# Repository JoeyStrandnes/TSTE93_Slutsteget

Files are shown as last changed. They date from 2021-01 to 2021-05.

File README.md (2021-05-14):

# TSTE93_Slutsteget
Projekt för kursen TSTE93

### Electronics

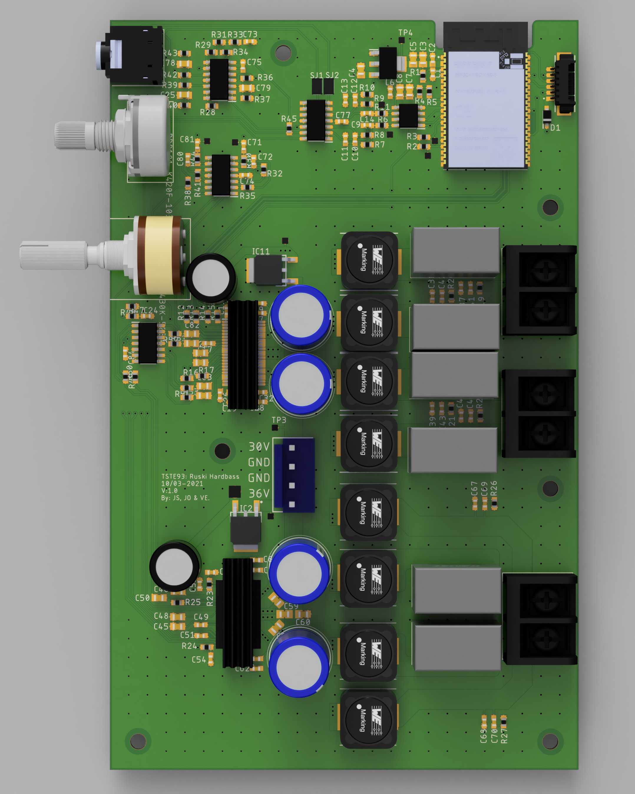
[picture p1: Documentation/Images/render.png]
Render


### Case

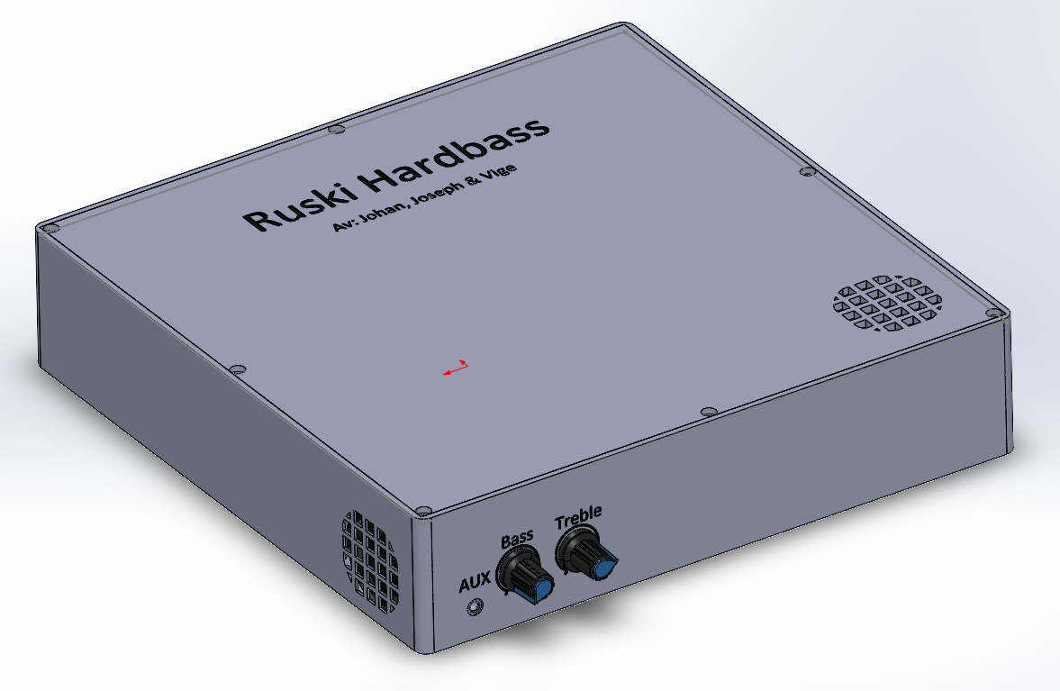
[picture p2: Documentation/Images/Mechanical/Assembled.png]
Case


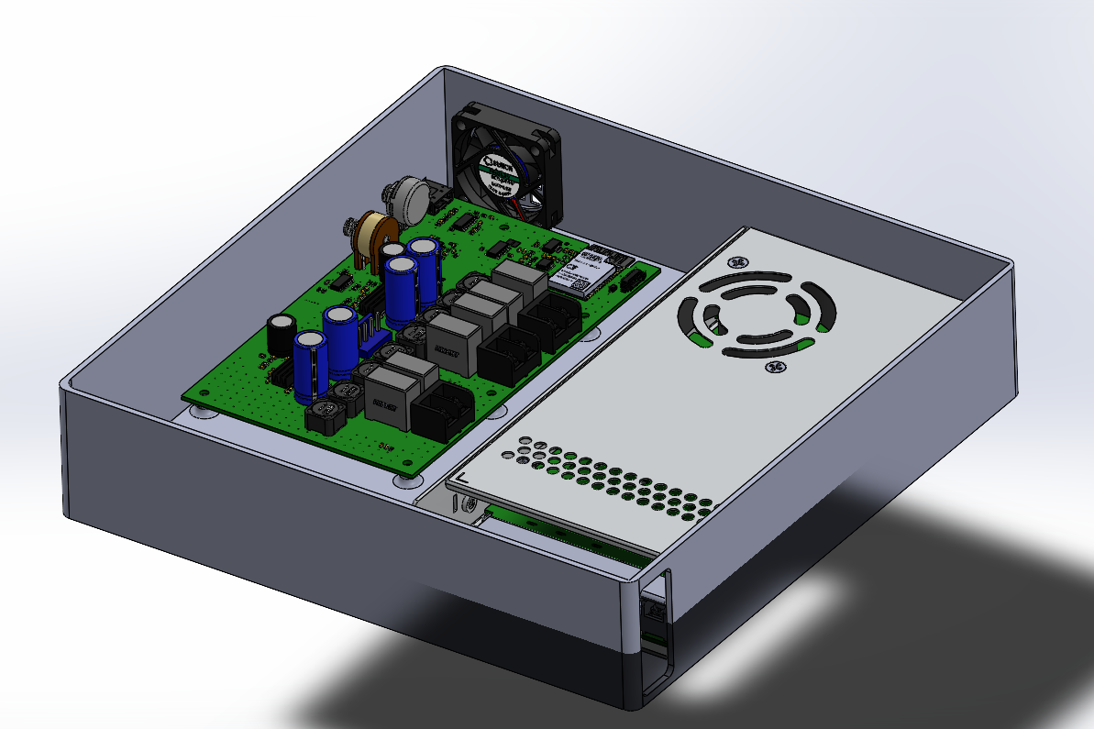
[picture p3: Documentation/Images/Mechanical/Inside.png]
Inside


### Functional diagram

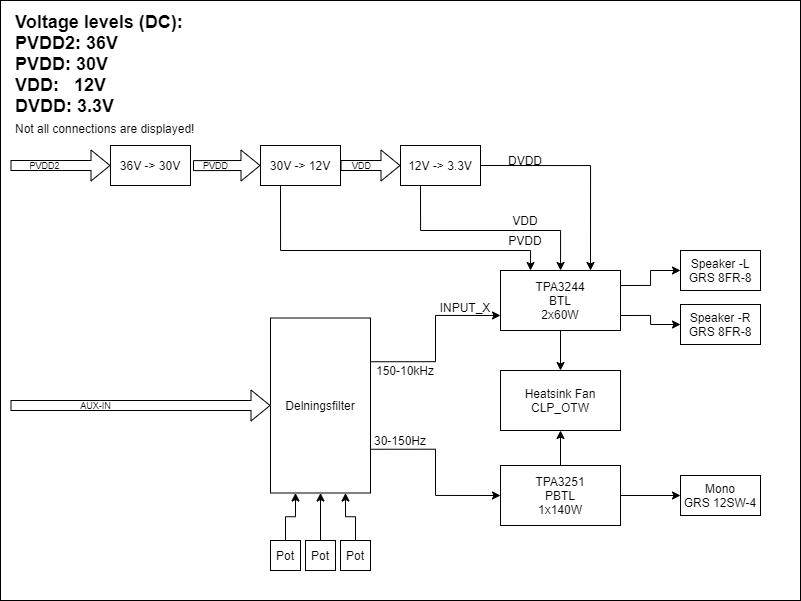
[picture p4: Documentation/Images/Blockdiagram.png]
Overview


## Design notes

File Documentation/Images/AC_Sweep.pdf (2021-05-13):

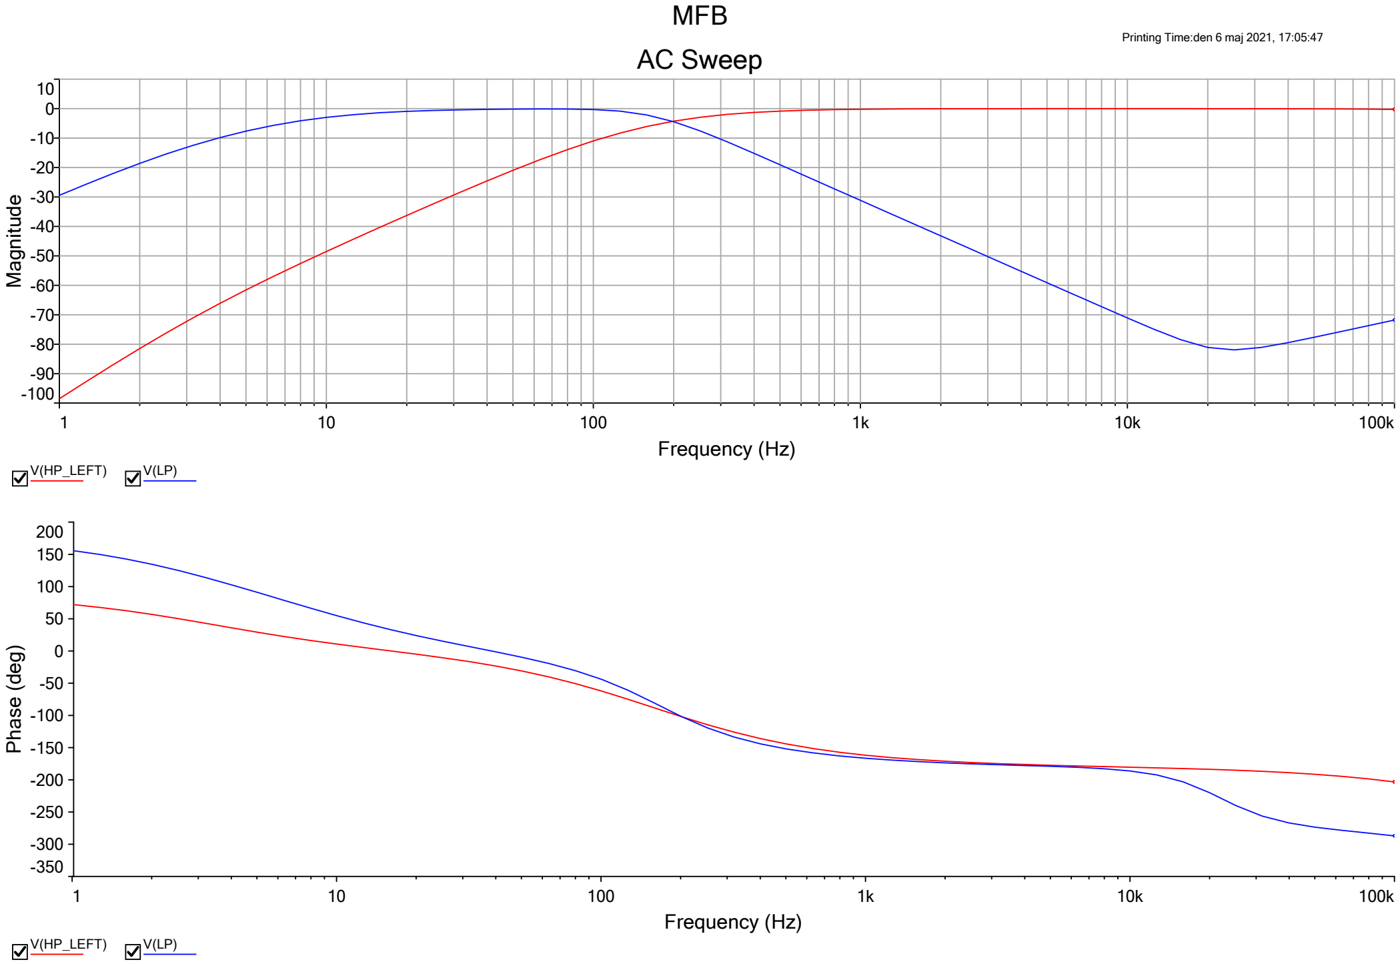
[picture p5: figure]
MFB; Printing Time:den 6 maj 2021, 17:05:47; V(HP_LEFT); AC Sweep; Frequency (Hz); 100k Magnitude; 100k Phase ⁽deg⁾

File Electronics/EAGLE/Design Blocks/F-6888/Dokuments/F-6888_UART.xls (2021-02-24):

UART通讯命令
模式 |  | 事件 | 指令 | 备注
LINEIN 模式 | RX | play/pause | BE 00 00 00 0c EB
 | RX | vol- | BE 00 00 00 12 EB
 | RX | vol+ | BE 00 00 00 13 EB
BT模式 | RX | play/pause | BE 00 00 00 0c EB
 | RX | next | BE 00 00 00 11 EB
 | RX | previous | BE 00 00 00 10 EB
 | RX | answer call | BE 00 00 00 16 EB
 | RX | cancel call | BE 00 00 00 16 EB
 | RX | reject call | BE 00 00 80 16 EB
 | RX | dial the last number | BE 00 00 20 16 EB
FM模式 | RX | vol- | BE 00 00 00 12 EB
 | RX | vol+ | BE 00 00 00 13 EB
 | RX | auto search | BE 00 00 00 0c EB
 | RX | NEXT channel | BE 00 00 00 11 EB
 | RX | PREV channel | BE 00 00 00 10 EB
 | RX | 0.1M NEXT tune | BE 00 00 00 21 EB
 | RX | 0.1M PREV tune | BE 00 00 00 22 EB
 | RX | find NEXT one and stop | BE 00 00 00 23 EB
 | RX | find PREV one and stop | BE 00 00 00 24 EB
 | RX | 请求读当前频率命令 | BE 70 00 00 06 EB
 | TX | 返馈给MCU频率值命令(TX) | BE 80 00 value2 value1 EB | 如101.6Mhz:发送值为1016，十六进制为0x3f8。则value1=0xf8;value2 = 0x03。
 | RX | 跳转到特定FM | BE 71 00 value2 value1 EB
 | RX | 请求读保存频道的信息 | BE 70 00 00 07 EB
其它命令 | RX | 请求读取当前模式命令 | BE 70 00 00 08 EB
 | RX | ENTER BT MODE | BE 70 00 00 01 EB(开机默认)
 | RX | ENTER U MODE | BE 70 00 00 02 EB
 | RX | ENTER SD MODE | BE 70 00 00 03 EB
 |  | ENTER FM MODE | BE 70 00 00 04 EB
 |  | ENTER AUX MODE | BE 70 00 00 05 EB

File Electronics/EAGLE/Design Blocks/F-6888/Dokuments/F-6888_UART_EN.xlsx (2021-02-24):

Mode |  | Event | Command | Notes
LINE IN | RX | Play/ pause

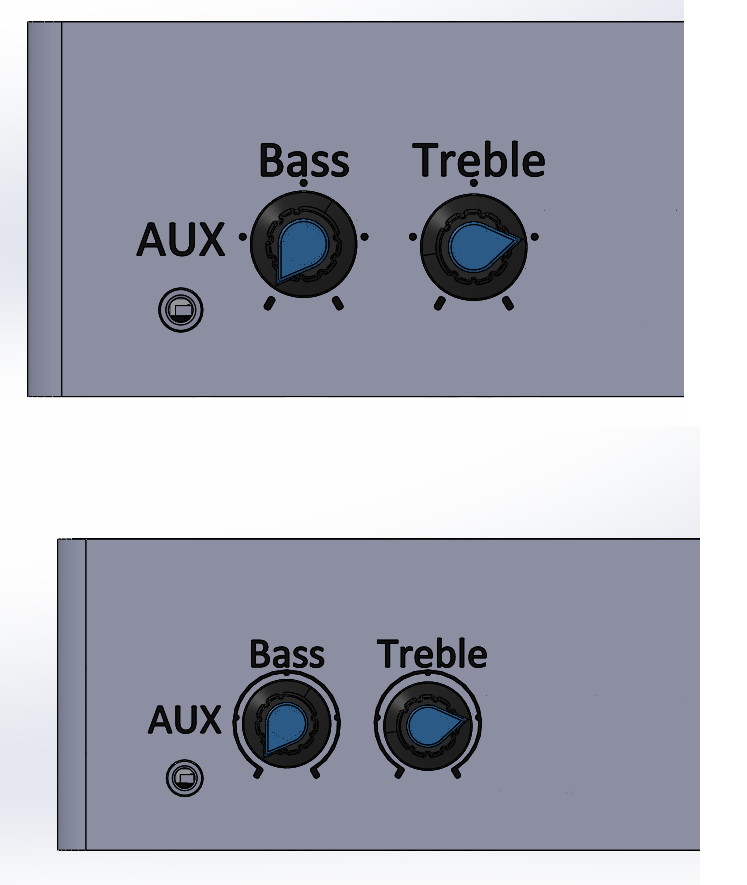
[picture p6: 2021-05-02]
Documentation/Images/Mechanical/Knobs.png

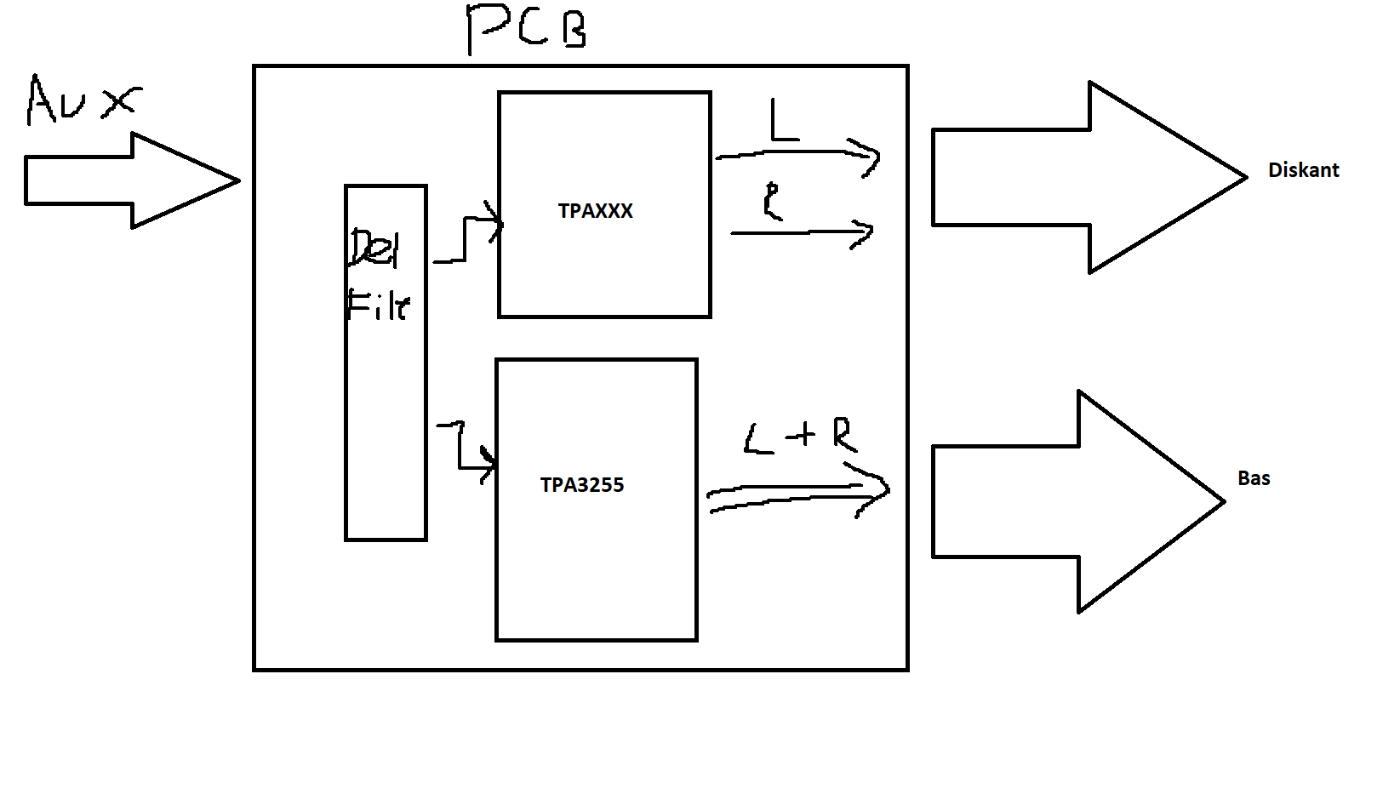
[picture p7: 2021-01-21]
Documentation/Images/Functional Overview.png

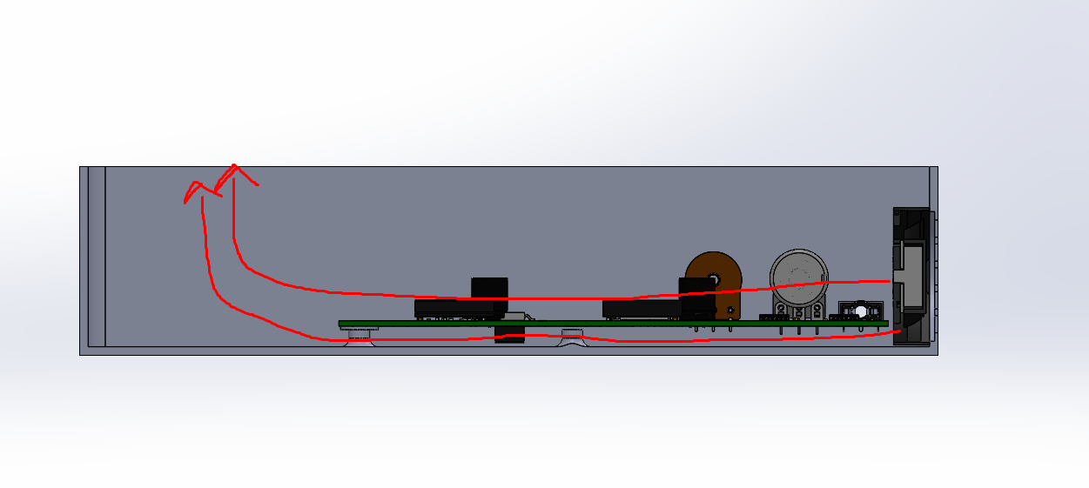
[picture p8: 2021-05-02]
Documentation/Images/Mechanical/Air_Flow.png

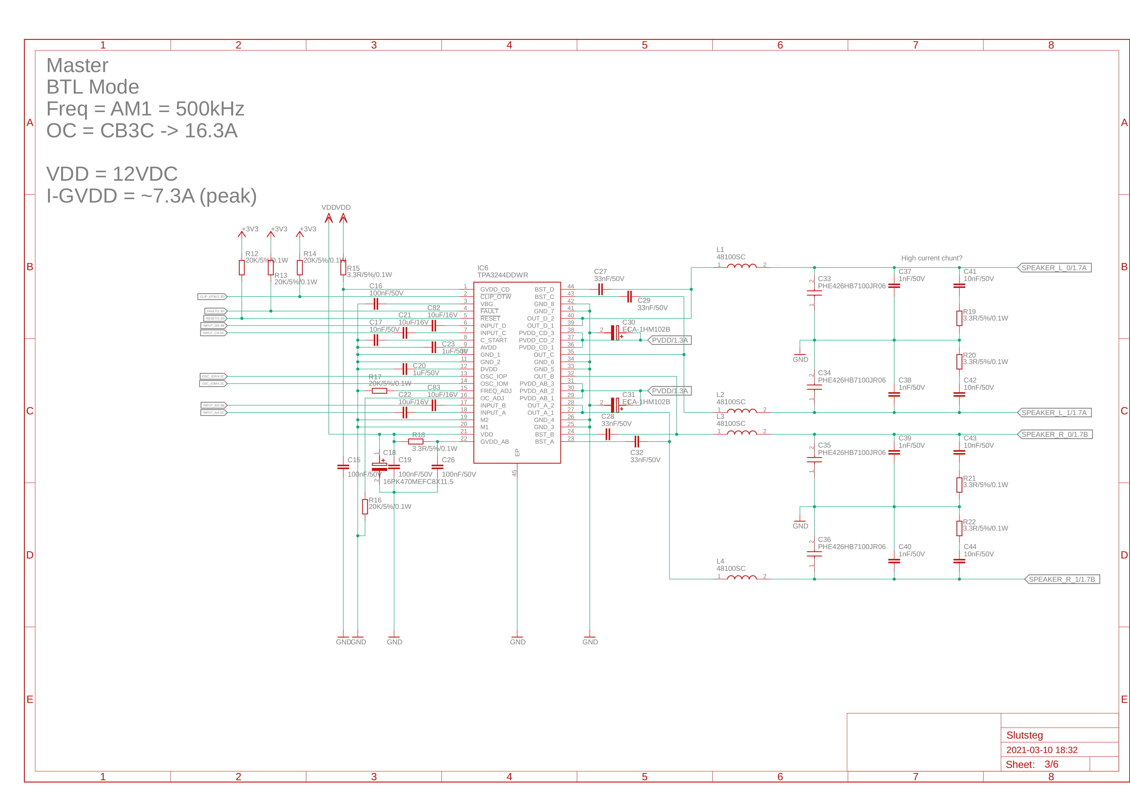
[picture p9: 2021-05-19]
Documentation/Schematic/Schematic-3.jpg

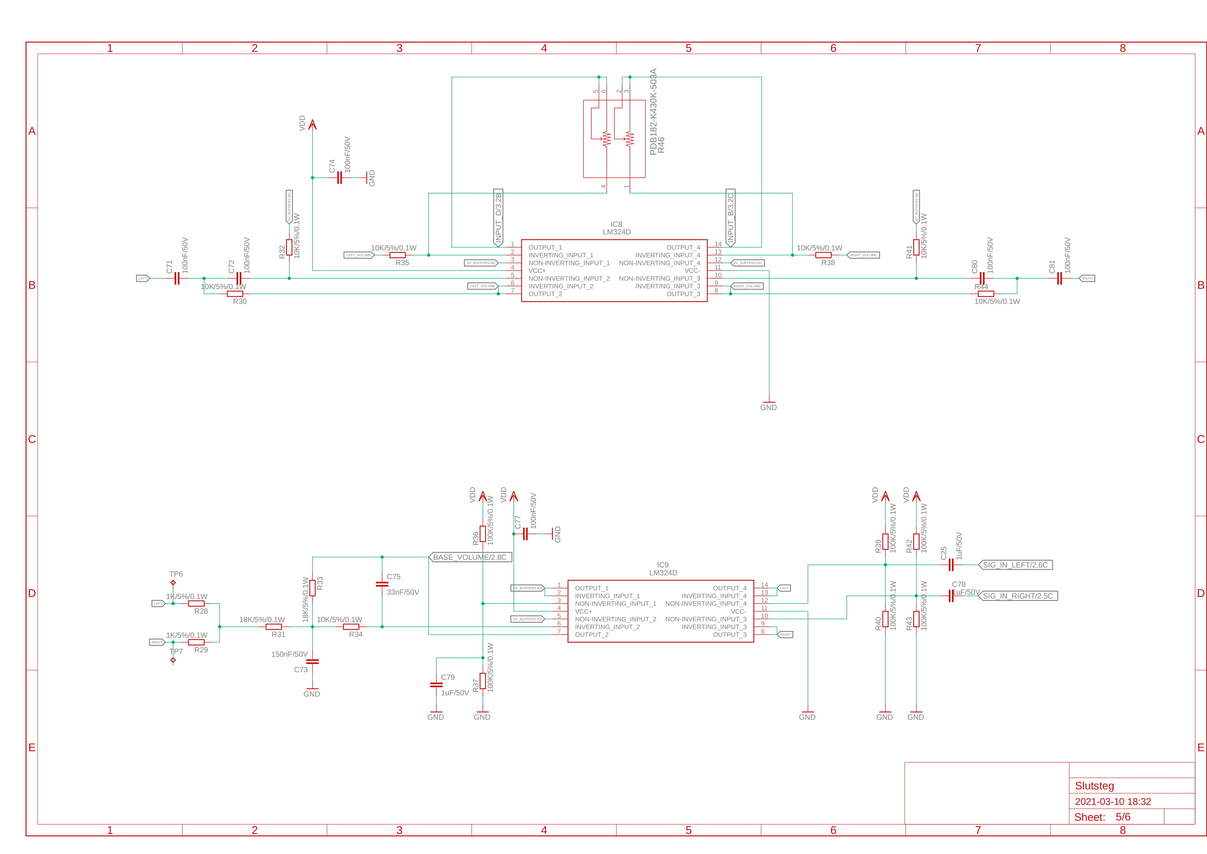
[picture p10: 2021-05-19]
Documentation/Schematic/Schematic-5.jpg

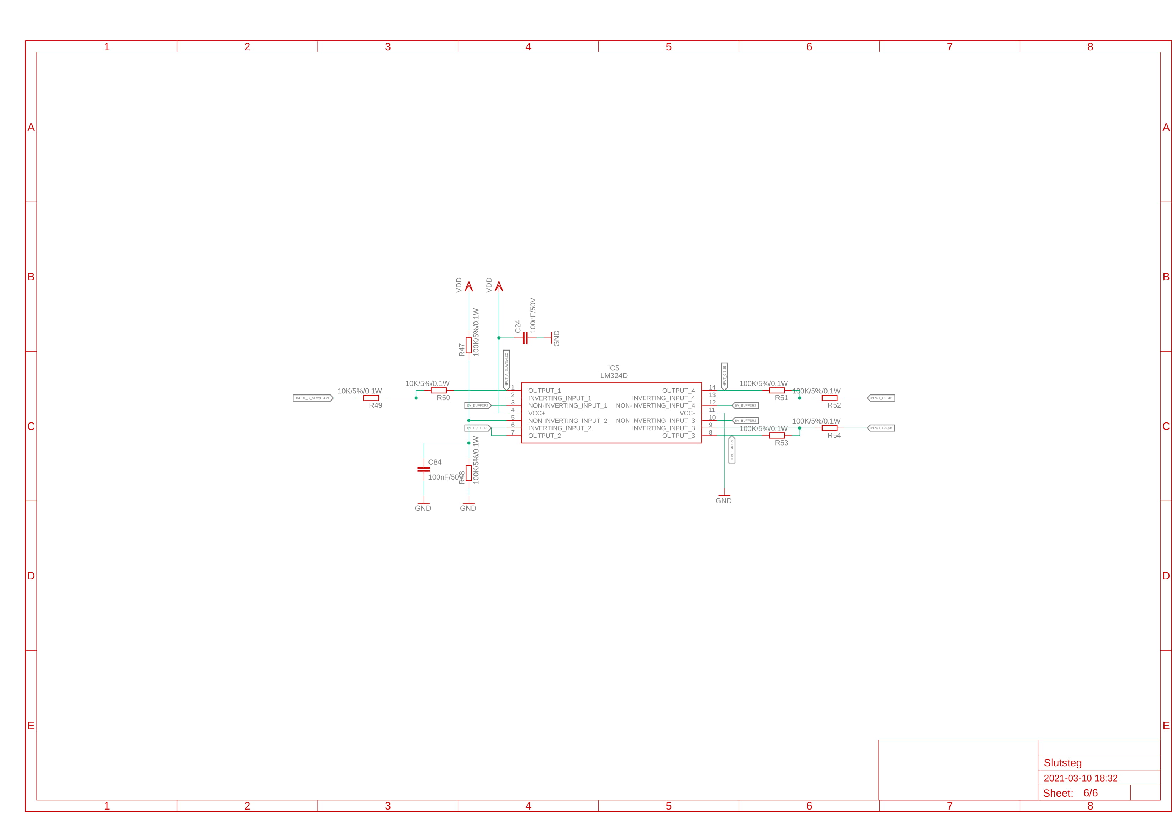
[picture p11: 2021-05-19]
Documentation/Schematic/Schematic-6.jpg

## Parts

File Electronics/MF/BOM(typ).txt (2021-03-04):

100 nF/50V https://www.elfa.se/en/ceramic-capacitor-100nf-50vdc-0603-10-kemet-c0603x104k5rac3316/p/30151488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

100k resistor: https://www.elfa.se/en/smd-resistor-100mw-100kohm-0603-vishay-crcw0603100kfkea/p/16059753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

10k resistor: https://www.elfa.se/en/smd-resistor-100mw-10kohm-0603-vishay-crcw060310k0fkea/p/16059729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

10 nF/50V: https://www.elfa.se/en/ceramic-capacitor-10nf-50vdc-0603-rnd-components-rnd-1500603b103j500nt/p/30086421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

10 uF/16V: https://www.elfa.se/en/ceramic-capacitor-10uf-16vdc-0805-10-kemet-c0805c106k4pactu/p/30031719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

150 nF/25V använder 50V: https://www.elfa.se/en/ceramic-capacitor-150nf-50vdc-0603-10-kemet-c0603c154k5ractu/p/30031633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

18K resistor: https://www.elfa.se/en/pulse-proof-high-power-thick-film-resistor-18kohm-0603-vishay-crcw060318k0fkeahp/p/30167967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

1K Resistor: https://www.elfa.se/en/smd-resistor-100mw-1kohm-0603-vishay-crcw06031k00fkea/p/16059705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

1 nF/50V: https://www.elfa.se/en/ceramic-capacitor-1nf-50vdc-0603-rnd-components-rnd-1500603b102j500nt/p/30086416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

1 uF/50V: https://www.elfa.se/en/ceramic-capacitor-1uf-50vdc-0805-10-rnd-components-rnd-1500805x105k500n3/p/30086815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

20K resistor: https://www.elfa.se/en/smd-resistor-100mw-20kohm-0603-vishay-crcw060320k0fkea/p/16059736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

3.3 resistor: https://www.elfa.se/en/smd-resistor-100mw-3ohm-0603-vishay-crcw06033r30fkea/p/30181579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

33 nF/50V: https://www.elfa.se/en/ceramic-capacitor-33nf-50vdc-0603-10-rnd-components-rnd-1500603b333k500nt/p/30086471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

74477010 (dyr, byter ut Josephs*) induktans: https://www.digikey.se/product-detail/en/w%C3%BCrth-elektronik/74477010/732-1223-1-ND/1639284

*Josephs: https://www.digikey.com/en/products/detail/murata-power-solutions-inc/48100SC/5798454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

B32652A3684J (kondensator): https://www.digikey.se/product-detail/en/epcos-tdk-electronics/B32652A3684J000/495-1299-ND/592875

Uber kondensatorer: https://www.digikey.com/en/products/detail/nichicon/UVY1H102MHD/2428007

OPAMPS: https://www.elfa.se/en/operational-amplifier-3mhz-20na-soic-st-lm324d/p/17346232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

Connectors: https://www.digikey.se/product-detail/en/on-shore-technology-inc/OSTYK33102030/ED2963-ND/1588785

Pottar: https://www.digikey.se/product-detail/en/bourns-inc/PDB181-K420K-503A2/PDB181-K420K-503A2-ND/699764

1 uF/250 VDC: https://www.elfa.se/en/capacitor-radial-1uf-160vac-250vdc-kemet-phe426hb7100jr06/p/16557664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

Schottky (kanske skippa): https://www.elfa.se/en/schottky-diode-500ma-20v-sod-123-st-stps0520z/p/30170847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

240 V Connector: https://www.elfa.se/en/inlet-combi-module-c14-panel-mount-straight-10a-250vac-rnd-connect-rnd-465-00787/p/30122457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

240V -> 36V Power supply: https://www.digikey.com/en/products/detail/cui-inc/VGS-350C-36/13538473

Ferrite core:

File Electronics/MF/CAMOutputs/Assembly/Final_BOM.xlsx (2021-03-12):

Qty | Parts | Value | Device | Package | Description | Styckpris | Köp-antal | Länk
1 | J1 | 532610671 | 532610671 | 532610671 | 1.25mm Pitch PicoBlade Header, Surface Mount
12 | R36, R37, R39, R40, R42, R43, R47, R48, R51, R52, R53, R54 | 100K/5%/0.1W | R-EU_R0603 | R0603 | RESISTOR, European symbol
19 | C1, C2, C6, C15, C16, C19, C24, C26, C51, C52, C53, C54, C71, C72, C74, C77, C80, C81, C84 | 100nF/50V | C-EUC0603 | C0603 | CAPACITOR, European symbol
22 | R1, R2, R3, R4, R5, R6, R7, R8, R9, R10, R11, R30, R32, R34, R35, R38, R41, R44, R45, R49, R50, R55 | 10K/5%/0.1W | R-EU_R0603 | R0603 | RESISTOR, European symbol
8 | C17, C41, C42, C43, C44, C49, C69, C70 | 10nF/50V | C-EUC0603 | C0603 | CAPACITOR, European symbol
11 | C3, C4, C5, C7, C8, C21, C22, C46, C50,C82, C83 | 10uF/16V | C-EUC0805 | C0805 | CAPACITOR, European symbol
1 | C73 | 150nF/50V | C-EUC0603 | C0603 | CAPACITOR, European symbol
1 | C18 | 16PK470MEFC8X11.5 | 16PK470MEFC8X11.5 | CAPPRD350W60D825H1300 | Rubycon 470uF 16 V dc Aluminium Electrolytic
2 | R31, R33 | 18K/5%/0.1W | R-EU_R0603 | R0603 | RESISTOR, European symbol
2 | R28, R29 | 1K/5%/0.1W | R-EU_R0603 | R0603 | RESISTOR, European symbol
12 | C9, C10, C11, C12, C13, C14, C37, C38, C39, C40, C67, C68 | 1nF/50V | C-EUC0603 | C0603 | CAPACITOR, European symbol
11 | C20, C23, C25, C45, C48, C56, C57, C59, C60, C78, C79 | 1uF/50V | C-EUC0805 | C0805 | CAPACITOR, European symbol
6 | R12, R13, R14, R16, R17, R25 | 20K/5%/0.1W | R-EU_R0603 | R0603 | RESISTOR, European symbol
10 | R15, R18, R19, R20, R21, R22, R23, R24, R26, R27 | 3.3R/5%/0.1W | R-EU_R0603 | R0603 | RESISTOR, European symbol
9 | C27, C28, C29, C32, C55, C58, C61, C62, C75 | 33nF/50V | C-EUC0603 | C0603 | CAPACITOR, European symbol
4 | L1, L2, L3, L4 | 48100SC | 48100SC | INDPM122122X600N | Murata Shielded Wire-wound SMD Inductor 10 u
4 | L5, L6, L7, L8 | 74477010 | 74477010 | WE-PD_1260/1245/1280/121054 | SMD-Shielded Power Inductors WE-PD
2 | C65, C66 | B32652A3684J | B32652A3684J | B32652A3684J | Film Capacitors 0.68uF 250volts 5%
1 | J4 | B4P-VH_LF__SN_ | B4P-VH_LF__SN_ | SHDR4W114P0X396_1X4_1578X850X9 | connector,multipole PCB use,B4P-VH,VH se JST
4 | C30, C31, C63, C64 | ECA-1HM102B | UVY1H102MHD | CAPPRD500W60D1300H2650 | Al Cap Radial VY series 1000uF 50V Nichicon
1 | C47 | ECA-1HM471B | 16PK470MEFC8X11.5 | CAPPRD350W60D825H1300 | Rubycon 470uF 16 V dc Aluminium Electrolytic
1 | IC3 | ESP32-WROVER-IE-4M | B ESP32-WROVER-IE__16MB_ | ESP32WROVERE8MB | WiFi Modules (802.11) IPEX antenna
1 | J2 | JW-PJ-307-4H | JW-PJ-307-4H | JW-PJ-307-4H | 3.5mm 3 pole audio connector
2 | IC2, IC11 | L78M12ABDT-TR | L78M12ABDT-TR | TO228P972X240-3N | L78M12ABDT-TR, Voltage Regulator, 0.5A 12 V,
4 | IC5, IC8, IC9, IC10 | LM324D | LM324D | SOIC127P600X175-14N | LM324D, Quad Operational Amplifier 1.3MHz 5
3 | CN1, CN2, CN3 | OSTYK33102030-2 | OSTYK33102030-2 | OSTYK33108030-2 | Skruvplint ljudutgång
1 | SW3 | PDB181-K420F-103A2 | PDB181-K420F-103A2 | SW_420F-103A2_BRN | Vridpotte 50k
1 | R46 | PDB182-K430K-503A | PDB182-K430K-503A | PDB18-2 | Vridpotte dual gang 50k
4 | C33, C34, C35, C36 | PHE426HB7100JR06 | PHE426HB7100JR06 | PHE426HB7100JR06 | Cap Film 1uF 250V PP 5% (18 X 9.5 X 17.5mm)
1 | Q1 | RK7002BMT116 | RK7002BMT116 | BSS64AHZGT116 | 2.5V Drive Nch MOSFET
1 | IC1 | SPX1117M3-L-3-3_TR | SPX1117M3-L-3-3_TR | SOT230P700X180-4N | LDO Regulator 3.3V 800mA 2.6-15V TO263-3
1 | D1 | STPS0520Z | STPS0520Z | SOD3816X145N | Schottky Diodes & Rectifiers 0.5 Amp 20 Volt
1 | IC4 | TM8211 | TM8211 | SOIC127P600X196-8N | 16 2 SOP-8_150mil DAC
1 | IC6 | TPA3244DDWR | TPA3244DDWR | SOP64P810X120-45N | 60W Stereo / 110W Peak PurePath Ultra-HD
1 | IC7 | TPA3251D2DDVR | TPA3251D2DDVR | SOP64P810X120-45N@1 | 175W Stereo / 350W Mono PurePath Ultra-HD
2 | U$3, U$4 | V5618A | V5618A | V5618A | Kylfläns DC-DC
2 | U$1, U$2 | V5618C | V5618C | V5618C | Kylfläns TPA32--

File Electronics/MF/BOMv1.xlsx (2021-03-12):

Qty | Parts | Value | Device | Package | Description | Styckpris | Extended pris | MOQ | MOQ + marginal | MOQ-ext | MOQ-ext-Marginal | ELFA/RS Art-nr | Inköps-länk
1 | J1 | 532610671 | 532610671 | 532610671 | 1.25mm Pitch PicoBlade Header, Surface Mount | 9.79 | 9.79 | 1 | 1 | 9.79 | 9.79 | 143-54-312 | https://www.elfa.se/en/picoblade-surface-mount-pcb-header-right-angle-contacts-rows-25mm-pitch-molex-53261-0671/p/14354312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
6 | R36, R37, R39, R40, R42, R43 | 100K/5%/0.1W | R-EU_R0603 | R0603 | RESISTOR, European symbol | 0.1127 | 0.6762 | 100 | 100 | 11.27 | 11.27 | 160-59-753 | https://www.elfa.se/en/smd-resistor-100mw-100kohm-0603-vishay-crcw0603100kfkea/p/16059753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
16 | C1, C2, C15, C16, C19, C26, C51, C52, C53, C54, C71, C72, C74, C77, C80, C81 | 100nF/50V | C-EUC0603 | C0603 | CAPACITOR, European symbol | 0.6592 | 10.5472 | 25 | 25 | 16.48 | 16.48 | 301-51-488 | https://www.elfa.se/en/ceramic-capacitor-100nf-50vdc-0603-10-kemet-c0603x104k5rac3316/p/30151488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
19 | R30, R32, R34, R35,R38, R41, R44, R45,R1, R2, R3, R4, R5,R6, R7, R8, R9, R10, R11 | 10K/5%/0.1W | R-EU_R0603 | R0603 | RESISTOR, European symbol | 0.1127 | 2.1413 | 100 | 100 | 11.27 | 11.27 | 160-59-729 | https://www.elfa.se/en/smd-resistor-100mw-10kohm-0603-vishay-crcw060310k0fkea/p/16059729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
8 | C17, C41, C42, C43,C44, C49, C69, C70 | 10nF/50V | C-EUC0603 | C0603 | CAPACITOR, European symbol | 0.1468 | 1.1744 | 100 | 100 | 14.68 | 14.68 | 300-86-421 | https://www.elfa.se/en/ceramic-capacitor-10nf-50vdc-0603-rnd-components-rnd-1500603b103j500nt/p/30086421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
12 | C3, C4, C5, C6, C7,C8, C21, C22, C24, C82,C46, C50 | 10uF/16V | C-EUC0805 | C0805 | CAPACITOR, European symbol | 1.96 | 23.52 | 12 | 15 | 23.52 | 29.4 | 300-31-719 | https://www.elfa.se/en/ceramic-capacitor-10uf-16vdc-0805-10-kemet-c0805c106k4pactu/p/30031719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
1 | C73 | 150nF/50V | C-EUC0603 | C0603 | CAPACITOR, European symbol | 1.319 | 1.319 | 25 | 25 | 32.975 | 32.975 | 801-5353 | https://se.rs-online.com/web/p/mlccs-multilayer-ceramic-capacitors/8015353
2 | C18,C47 | 16PK470MEFC8X11.5 | 16PK470MEFC8X11.5 | CAPPRD350W60D825H1300 | Rubycon 470uF 16 V dc Aluminium Electrolytic | 2.91 | 5.82 | 2 | 4 | 5.82 | 11.64 |  | https://www.digikey.se/products/en?keywords=16PK470MEFC8X11.5
2 | R31, R33 | 18K/5%/0.1W | R-EU_R0603 | R0603 | RESISTOR, European symbol | 1.04 | 2.08 | 10 | 10 | 10.4 | 10.4 | 301-67-967 | https://www.elfa.se/en/pulse-proof-high-power-thick-film-resistor-18kohm-0603-vishay-crcw060318k0fkeahp/p/30167967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
2 | R28, R29 | 1K/5%/0.1W | R-EU_R0603 | R0603 | RESISTOR, European symbol | 0.1106 | 0.2212 | 2 | 5 | 0.2212 | 0.553 | 160-59-705 | https://www.elfa.se/en/smd-resistor-100mw-1kohm-0603-vishay-crcw06031k00fkea/p/16059705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
12 | C9, C10, C11, C12,C13, C14, C37, C38, C39,C40, C67, C68 | 1nF/50V | C-EUC0603 | C0603 | CAPACITOR, European symbol | 0.1411 | 1.6932 | 100 | 100 | 14.11 | 14.11 | 300-86-416 | https://www.elfa.se/en/ceramic-capacitor-1nf-50vdc-0603-rnd-components-rnd-1500603b102j500nt/p/30086416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
11 | C20, C23, C25, C45,C48, C56, C57, C59, C60,C78, C79 | 1uF/50V | C-EUC0805 | C0805 | CAPACITOR, European symbol | 2.143 | 23.573 | 11 | 14 | 23.573 | 30.002 | 788-3054 | https://se.rs-online.com/web/p/mlccs-multilayer-ceramic-capacitors/7883054
6 | R12, R13, R14, R16,R17, R25 | 20K/5%/0.1W | R-EU_R0603 | R0603 | RESISTOR, European symbol | 0.1127 | 0.6762 | 100 | 100 | 11.27 | 11.27 | 160-59-736 | https://www.elfa.se/en/smd-resistor-100mw-20kohm-0603-vishay-crcw060320k0fkea/p/16059736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
10 | R15, R18, R19, R20,R21, R22, R23, R24, R26,R27 | 3.3R/5%/0.1W | R-EU_R0603 | R0603 | RESISTOR, European symbol | 0.2604 | 2.604 | 50 | 50 | 13.02 | 13.02 | 301-81-579 | https://www.elfa.se/en/smd-resistor-100mw-3ohm-0603-vishay-crcw06033r30fkea/p/30181579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
9 | C27, C28, C29, C32,C55, C58, C61, C62, C75 | 33nF/50V | C-EUC0603 | C0603 | CAPACITOR, European symbol | 0.0998 | 0.8982 | 100 | 100 | 9.98 | 9.98 | 300-86-471 | https://www.elfa.se/en/ceramic-capacitor-33nf-50vdc-0603-10-rnd-components-rnd-1500603b333k500nt/p/30086471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
4 | L1, L2, L3, L4 | 48100SC | 48100SC | INDPM122122X600N | Murata Shielded Wire-wound SMD Inductor 10 u | 4.32 | 17.28 | 4 | 5 | 17.28 | 21.6 |  | https://www.digikey.se/product-detail/en/murata-power-solutions-inc/48100SC/811-3835-1-ND/9693300
4 | L5, L6, L7, L8 | 74477010 | 74477010 | WE-PD_1260/1245/1280/121054 | SMD-Shielded Power Inductors WE-PD | 18.7 | 74.8 | 4 | 5 | 74.8 | 93.5 |  | https://www.digikey.se/product-detail/en/w%C3%BCrth-elektronik/74477010/732-1223-1-ND/1639284
2 | C65, C66 | B32652A3684J | B32652A3684J | B32652A3684J | Film Capacitors 0.68uF 250volts 5% | 8.06 | 16.12 | 2 | 4 | 16.12 | 32.24 |  | https://www.digikey.se/product-detail/en/epcos-tdk-electronics/B32652A3684J000/495-1299-ND/592875
4 | C30, C31, C63, C64 | ECA-1HM102B | UVY1H102MHD | CAPPRD500W60D1300H2650 | Al Cap Radial VY series 1000uF 50V Nichicon | 7.81 | 31.24 | 4 | 5 | 31.24 | 39.05 |  | https://www.digikey.se/product-detail/en/nichicon/UVY1H102MHD/UVY1H102MHD-ND/2428007
1 | IC3 | ESP32-WROVER-IE-4MB | ESP32-WROVER-IE__16MB_ | ESP32WROVERE8MB | WiFi Modules (802.11) IPEX antenna |  | 0 |  | 0 | 0 | 0
1 | J2 | JW-PJ-307-4H | JW-PJ-307-4H | JW-PJ-307-4H | 3.5mm 3pole audio connector | 10.022 | 10.022 | 5 | 5 | 50.11 | 50.11 | 913-1009 | https://se.rs-online.com/web/p/jack-plugs-sockets/9131009
1 | IC11 | L78M12ABDT-TR | L78M12ABDT-TR | TO228P972X240-3N | L78M12ABDT-TR, Voltage Regulator, 0.5A 12 V, | 6.15 | 6.15 | 5 | 5 | 30.75 | 30.75 | 300-18-763 | https://www.elfa.se/en/linear-fixed-voltage-regulator-12v-500ma-dpak-st-l78m12abdt-tr/p/30018763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
3 | IC8, IC9, IC10 | LM324D | LM324D | SOIC127P600X175-14N | LM324D, Quad Operational Amplifier 1.3MHz 5 | 3.76 | 11.28 | 10 | 10 | 37.6 | 37.6 | 173-46-232 | https://www.elfa.se/en/operational-amplifier-3mhz-20na-soic-st-lm324d/p/17346232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
3 | CN1, CN2, CN3 | OSTYK33102030-2 | OSTYK33102030-2 | OSTYK33108030-2 |  | 10.39 | 31.17 | 3 | 3 | 31.17 | 31.17 |  | https://www.digikey.se/product-detail/en/on-shore-technology-inc/OSTYK33102030/ED2963-ND/1588785
1 | SW1, SW2, SW3 | PDB181-K420F-103A2 | PDB181-K420F-103A2 | SW_420F-103A2_BRN | POT 50K OHM 0.06W CARBON LOG | 10.14 | 10.14 | 1 | 1 | 10.14 | 10.14 |  | https://www.digikey.se/product-detail/en/bourns-inc/PDB181-K420K-503A2/PDB181-K420K-503A2-ND/699764
4 | C33, C34, C35, C36 | PHE426HB7100JR06 | PHE426HB7100JR06 | PHE426HB7100JR06 | Cap Film 1uF 250V PP 5% (18 X 9.5 X 17.5mm) | 13.8 | 55.2 | 4 | 5 | 55.2 | 69 | 165-57-664 | https://www.elfa.se/en/capacitor-radial-1uf-160vac-250vdc-kemet-phe426hb7100jr06/p/16557664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
1 | IC1 | SPX1117M3-L-3-3_TR | SPX1117M3-L-3-3_TR | SOT230P700X180-4N | LDO Regulator 3.3V 800mA 2.6-15V TO263-3 | 3.49 | 3.49 | 1 | 1 | 3.49 | 3.49 |  | https://www.digikey.se/product-detail/en/maxlinear-inc/SPX1117M3-L-3-3-TR/1016-1848-1-ND/3586565
1 | D1 | STPS0520Z | STPS0520Z | SOD3816X145N | Schottky Diodes & Rectifiers 0.5 Amp 20 Volt | 2.99 | 2.99 | 1 | 1 | 2.99 | 2.99 |  | https://www.digikey.se/product-detail/en/stmicroelectronics/STPS0520Z/497-3205-1-ND/654548
1 | IC4 | TM8211 | TM8211 | SOIC127P600X196-8N | 16 2 SOP-8_150mil Digital To Analog Converte |  | 0 |  | 0 | 0 | 0
1 | IC6 | TPA3244DDWR | TPA3244DDWR | SOP64P810X120-45N | 60W Stereo / 110W Peak PurePath Ultra-HD Ana | 46.95 | 46.95 | 1 | 1 | 46.95 | 46.95 |  | https://www.digikey.se/product-detail/en/texas-instruments/TPA3244DDWR/296-45175-1-ND/6579551
1 | IC7 | TPA3251D2DDVR | TPA3251D2DDVR | SOP64P810X120-45N@1 | 175W Stereo / 350W Mono PurePath Ultra-HD, A | 63.9 | 63.9 | 1 | 1 | 63.9 | 63.9 |  | https://www.digikey.se/product-detail/en/texas-instruments/TPA3251D2DDVR/296-47860-1-ND/8133209
 |  |  |  |  |  |  | 0 |  |  | 0 | 0
1 |  | RND 465-00787 |  |  | connector | 20.7 | 20.7 | 1 | 1 | 20.7 | 20.7 | 301-22-457 | https://www.elfa.se/en/inlet-combi-module-c14-rnd-connect-rnd-465-00787/p/30122457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
1 |  | VGS-350C-36 |  |  | power supply | 332.4 | 332.4 | 1 | 1 | 332.4 | 332.4 |  | https://www.digikey.se/product-detail/en/cui-inc/VGS-350C-36/102-VGS-350C-36-ND/13538473
1 | SW? | PDB182-K430K-503A |  |  | DUAL POT 50K OHM 0.06W CARBON LOG | 15.87 | 15.87 | 1 | 1 | 15.87 | 15.87 |  | https://www.digikey.se/products/en?keywords=PDB182-K430K-503A
 |  |  |  |  | FERRIT |  | 0
 |  | B4P-VH(LF)(SN) |  |  | PVDD connector Hane | 1.5 |  | 1 | 1 |  |  |  | https://www.digikey.se/product-detail/en/jst-sales-america-inc/B4P-VH-LF-SN/455-1641-ND/926549?cur=SEK&lang=en
 |  | VHR-4M |  |  | PVDD connector Hona | 2.41 |  |  |  |  |  |  | https://www.digikey.se/product-detail/en/jst-sales-america-inc/VHR-4M/455-3990-ND/9924201?cur=SEK&lang=en
 |  | Black 16 AWG Jumper Lead Socket to Socket Tin 6.00" |  |  | Crimpade PVDD kablar | 5.65 |  |  |  |  |  |  | https://www.digikey.se/products/en?keywords=ASVHSVH16K152
 |  | TG-A6200-10-5-0.5 |  |  | Thermal Pad | 0.83 |  |  |  |  |  |  | https://www.digikey.se/products/en?keywords=TG-A6200-10-5-0.5
 |  | HA40101V4-1000U-A99 |  |  | Fan Tubeaxial 12VDC Square - 40mm L x 40mm | 22.6 |  |  |  |  |  |  | https://www.digikey.se/products/en?keywords=HA40101V4-1000U-A99
 |  | V5618C |  |  | HEATSINK ALUM ANOD | 7.15 |  |  |  |  |  |  | https://www.digikey.se/products/en?keywords=V5618C
 |  | APT15DQ60KG |  |  | Värm-upp-huset-Dioder | 4.49 |  |  |  |  |  |  | https://www.digikey.se/products/sv?keywords=APT15DQ60KG
150 |  |  |  |  |  |  | 467.4659 | Allt som allt: |  | 1049.0892 | 1128.3
 |  |  |  |  |  |  |  | Skolan pyntar: |  | 396.9192 | 423.36
 |  |  |  |  |  |  |  | Vi pyntar: |  | 652.17 | 704.94

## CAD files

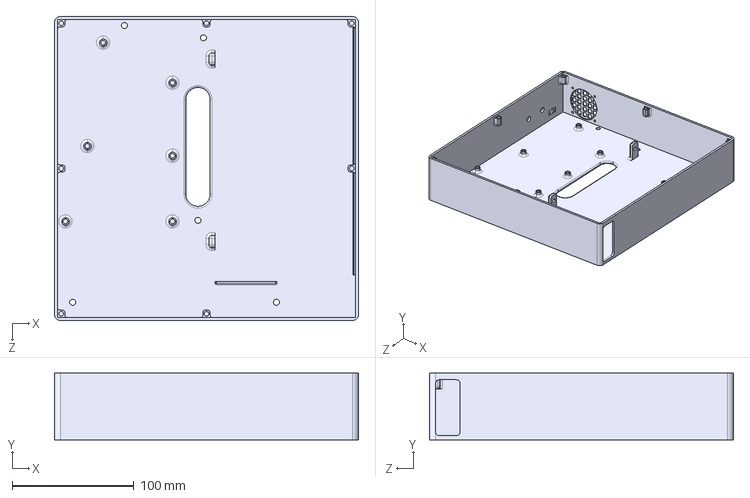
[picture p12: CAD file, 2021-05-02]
Mechanical/STEP/Housing_Bottom.STEP
250.0 x 55.0 x 250.0 mm

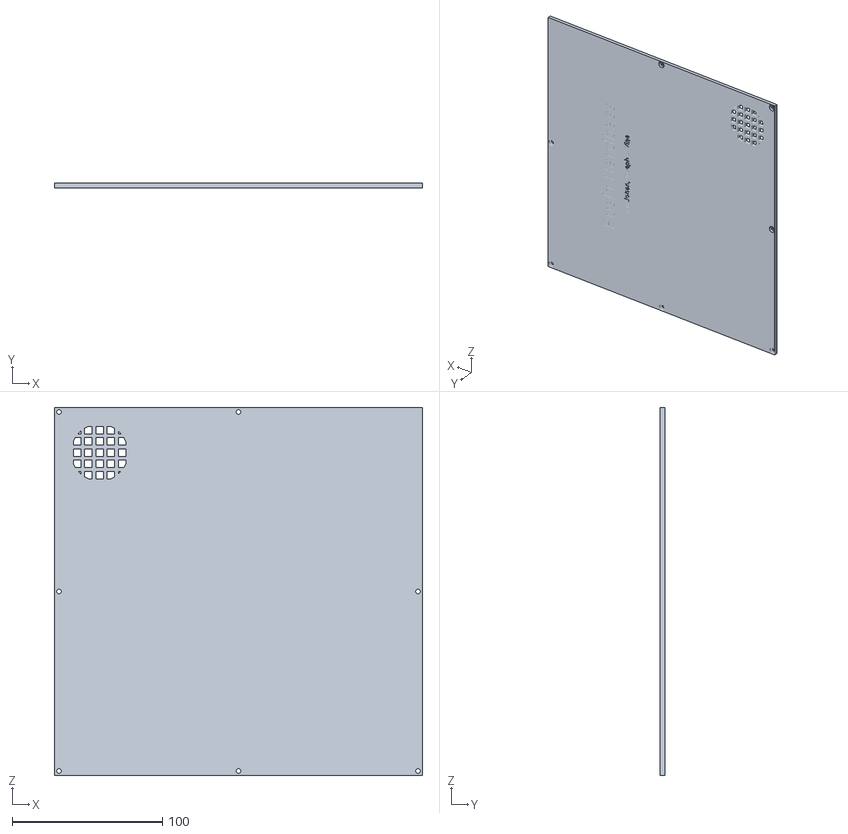
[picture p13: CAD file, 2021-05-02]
Mechanical/STL/Housing_Top.STL
245.0 x 3.00 x 245.0

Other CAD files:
Mechanical/STL/Housing_Bottom.STL

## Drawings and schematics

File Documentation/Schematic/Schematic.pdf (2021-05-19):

A

A

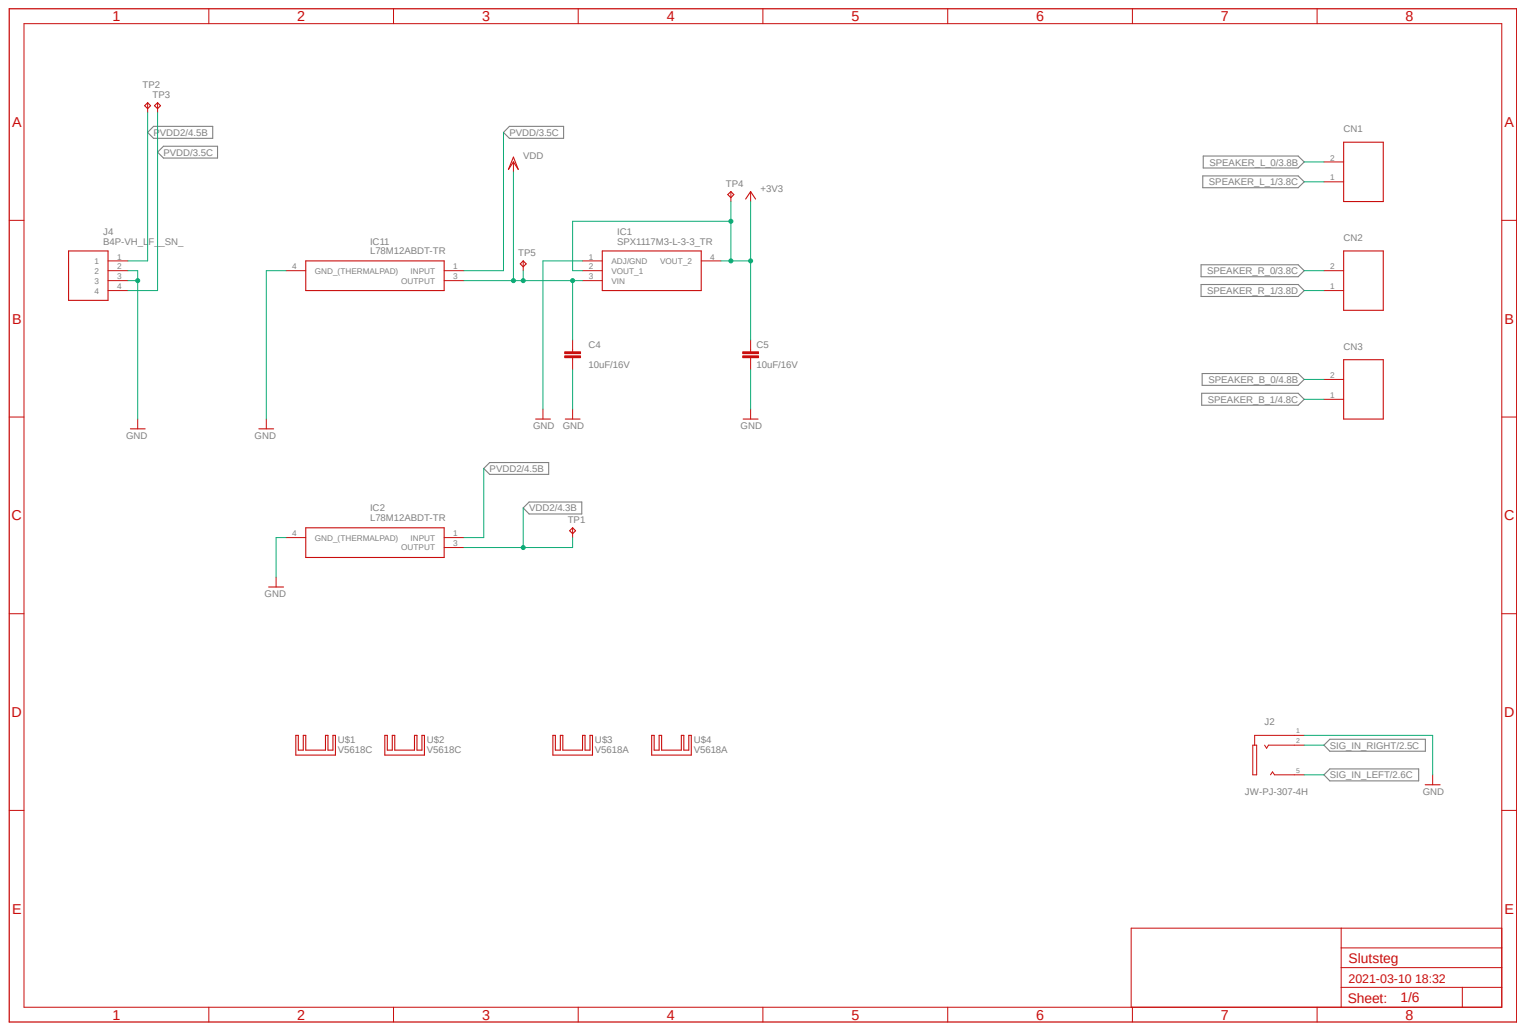
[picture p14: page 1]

# Input Programming Conn

A

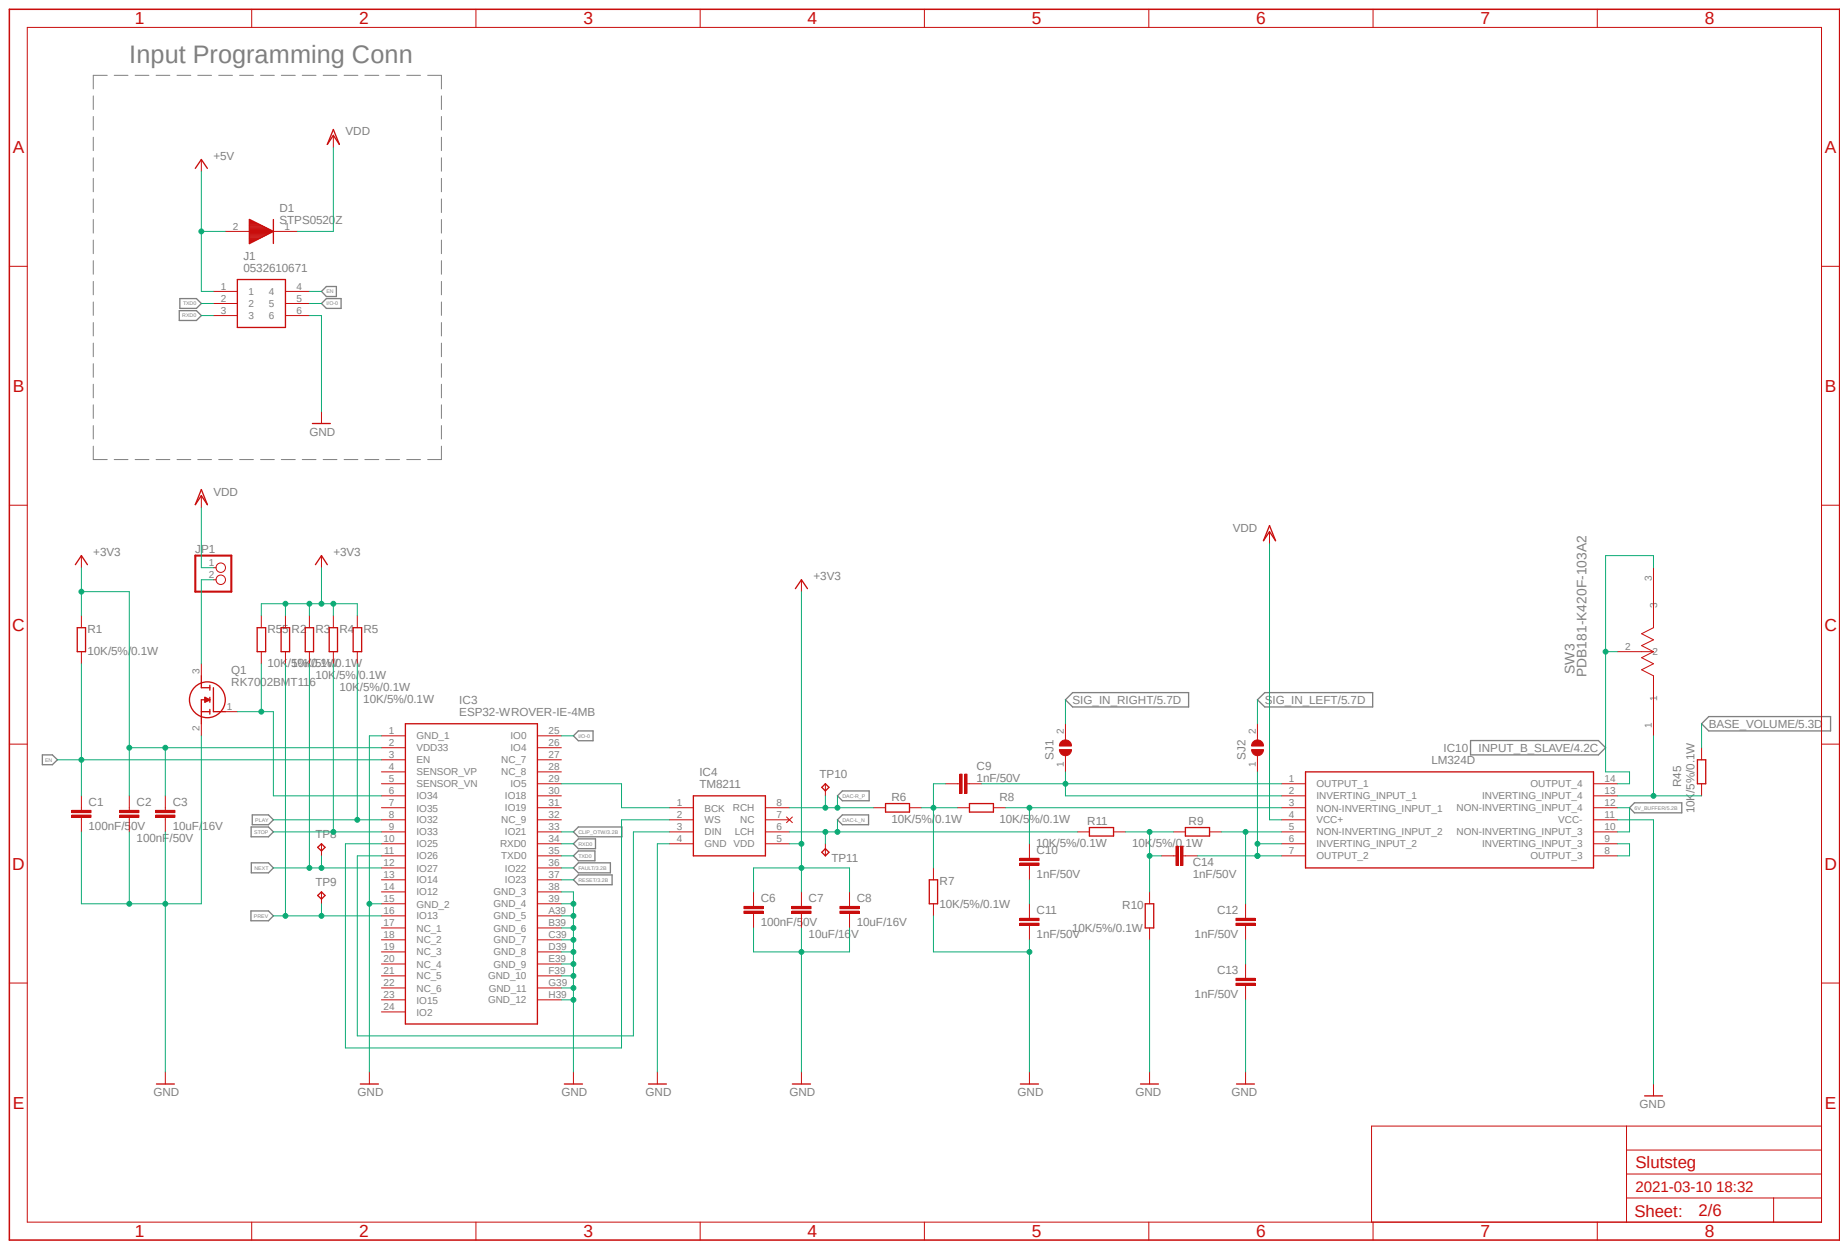
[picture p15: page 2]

TP9 | | IO14 13 IO12 14 GND_2 15

# Master BTL Mode

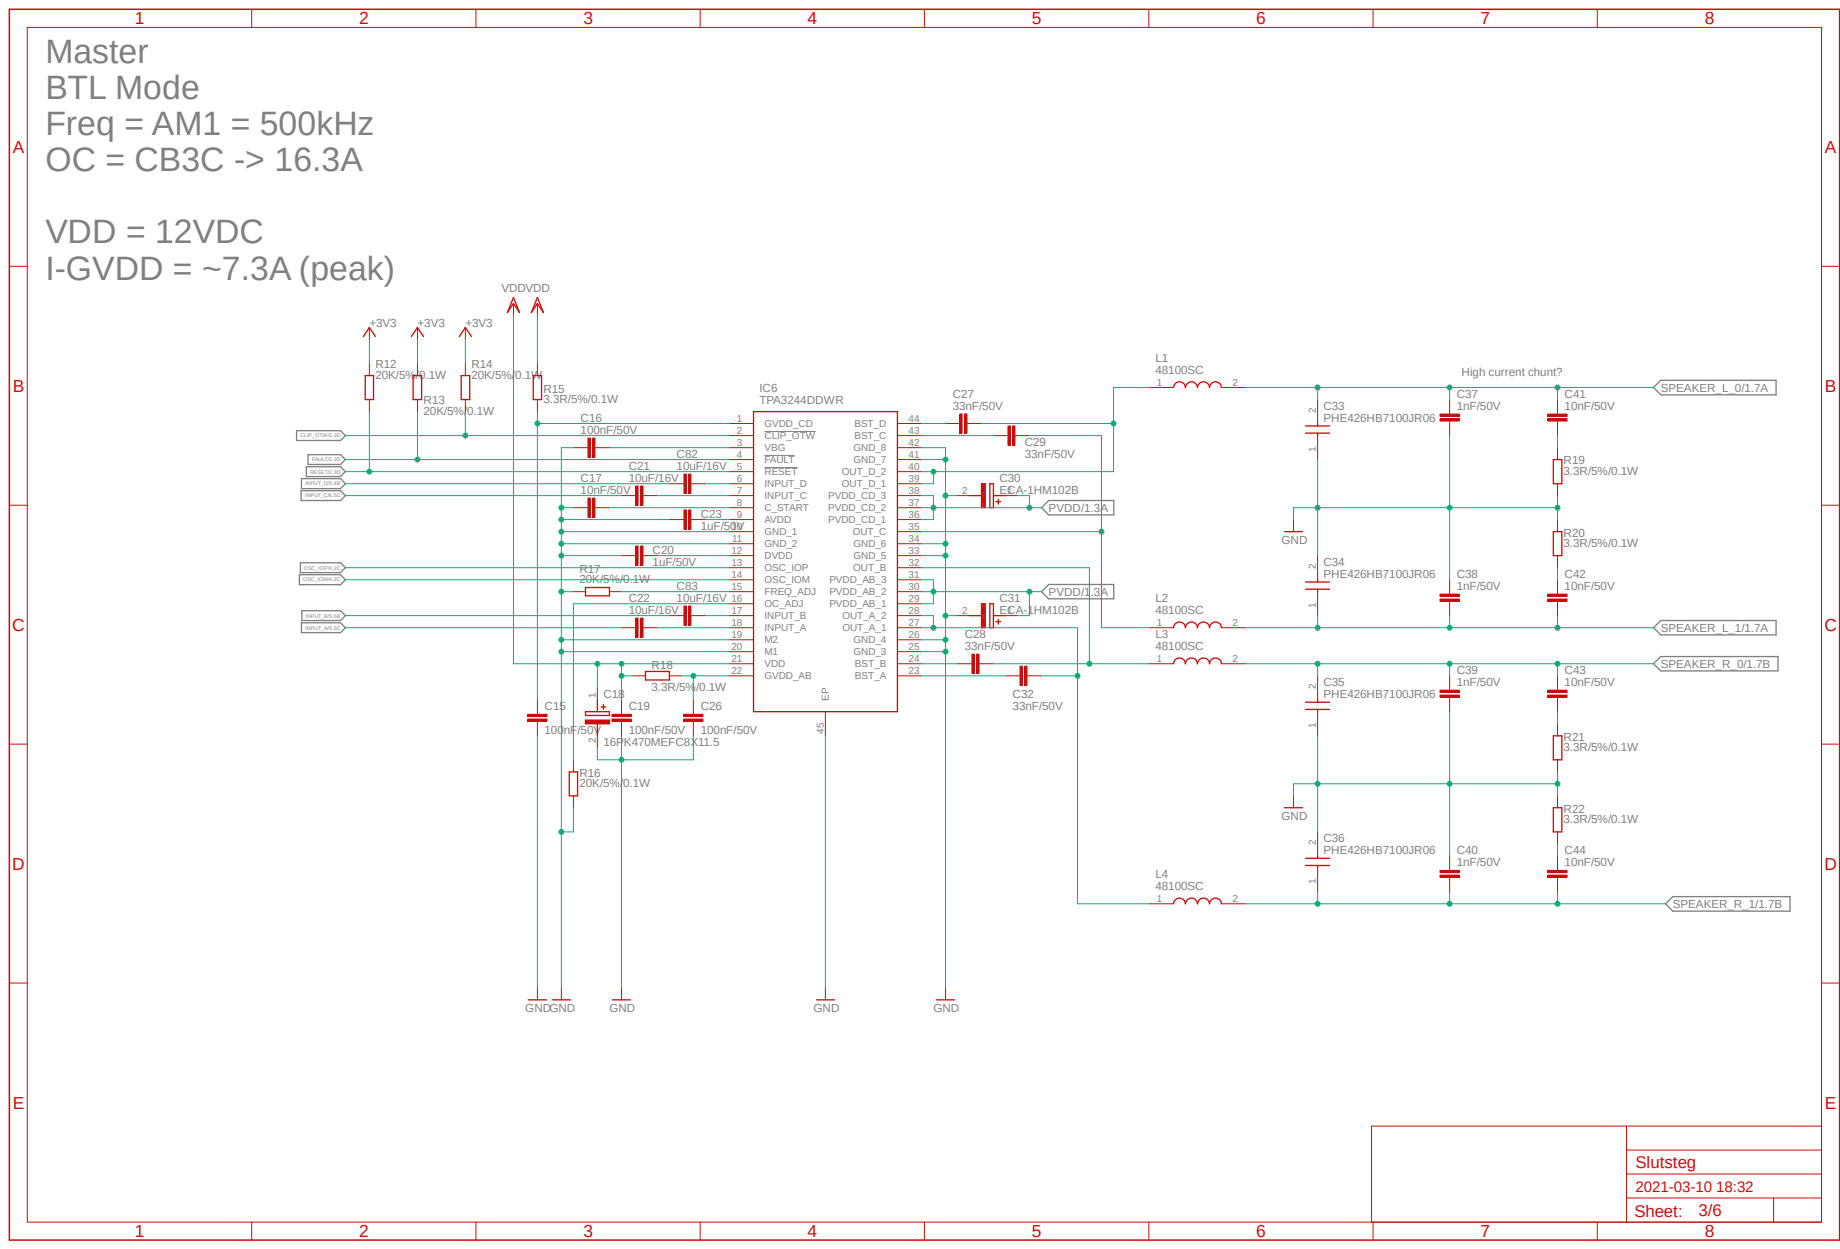
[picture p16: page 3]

A

A

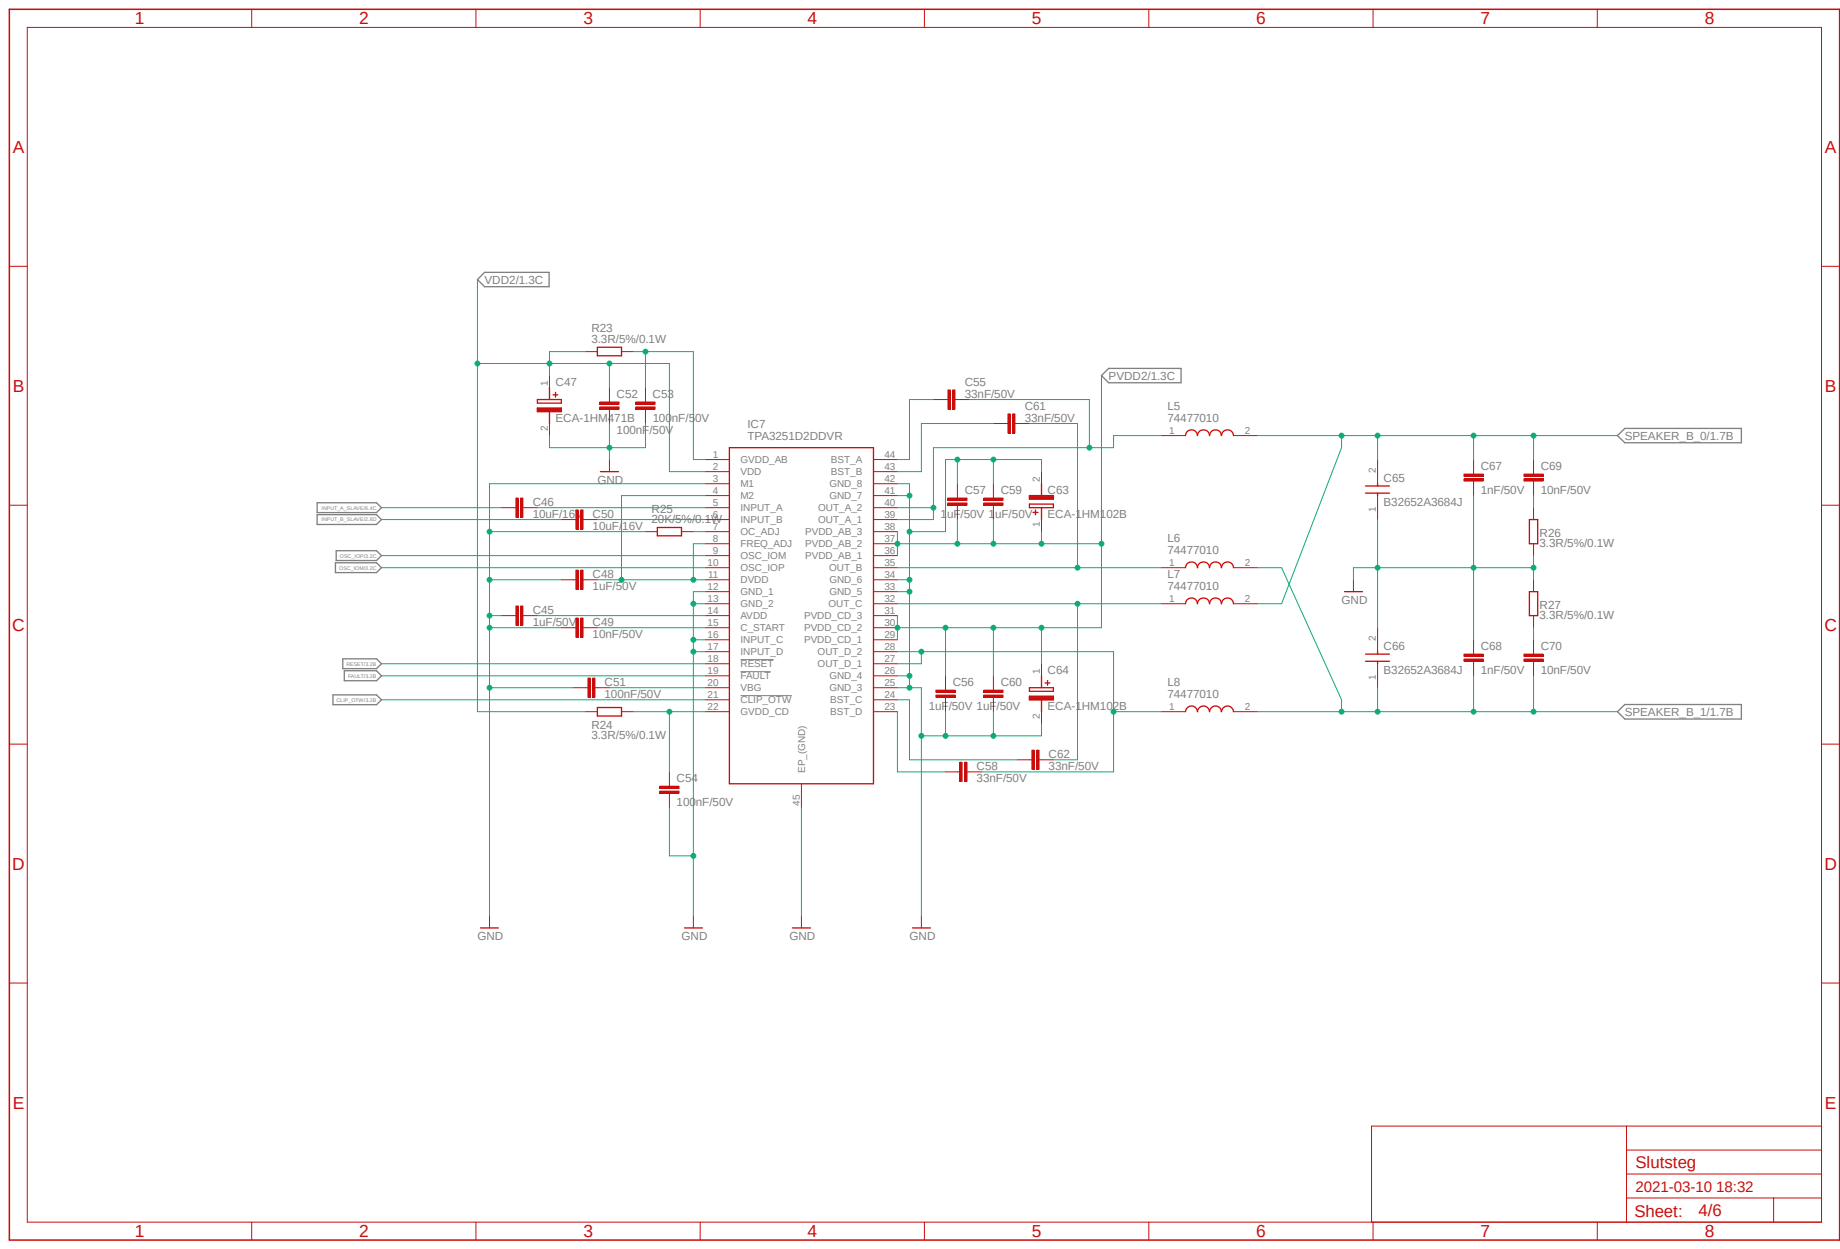
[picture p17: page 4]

# RIGHT_VOLUME INPUT_B/3.2C

A

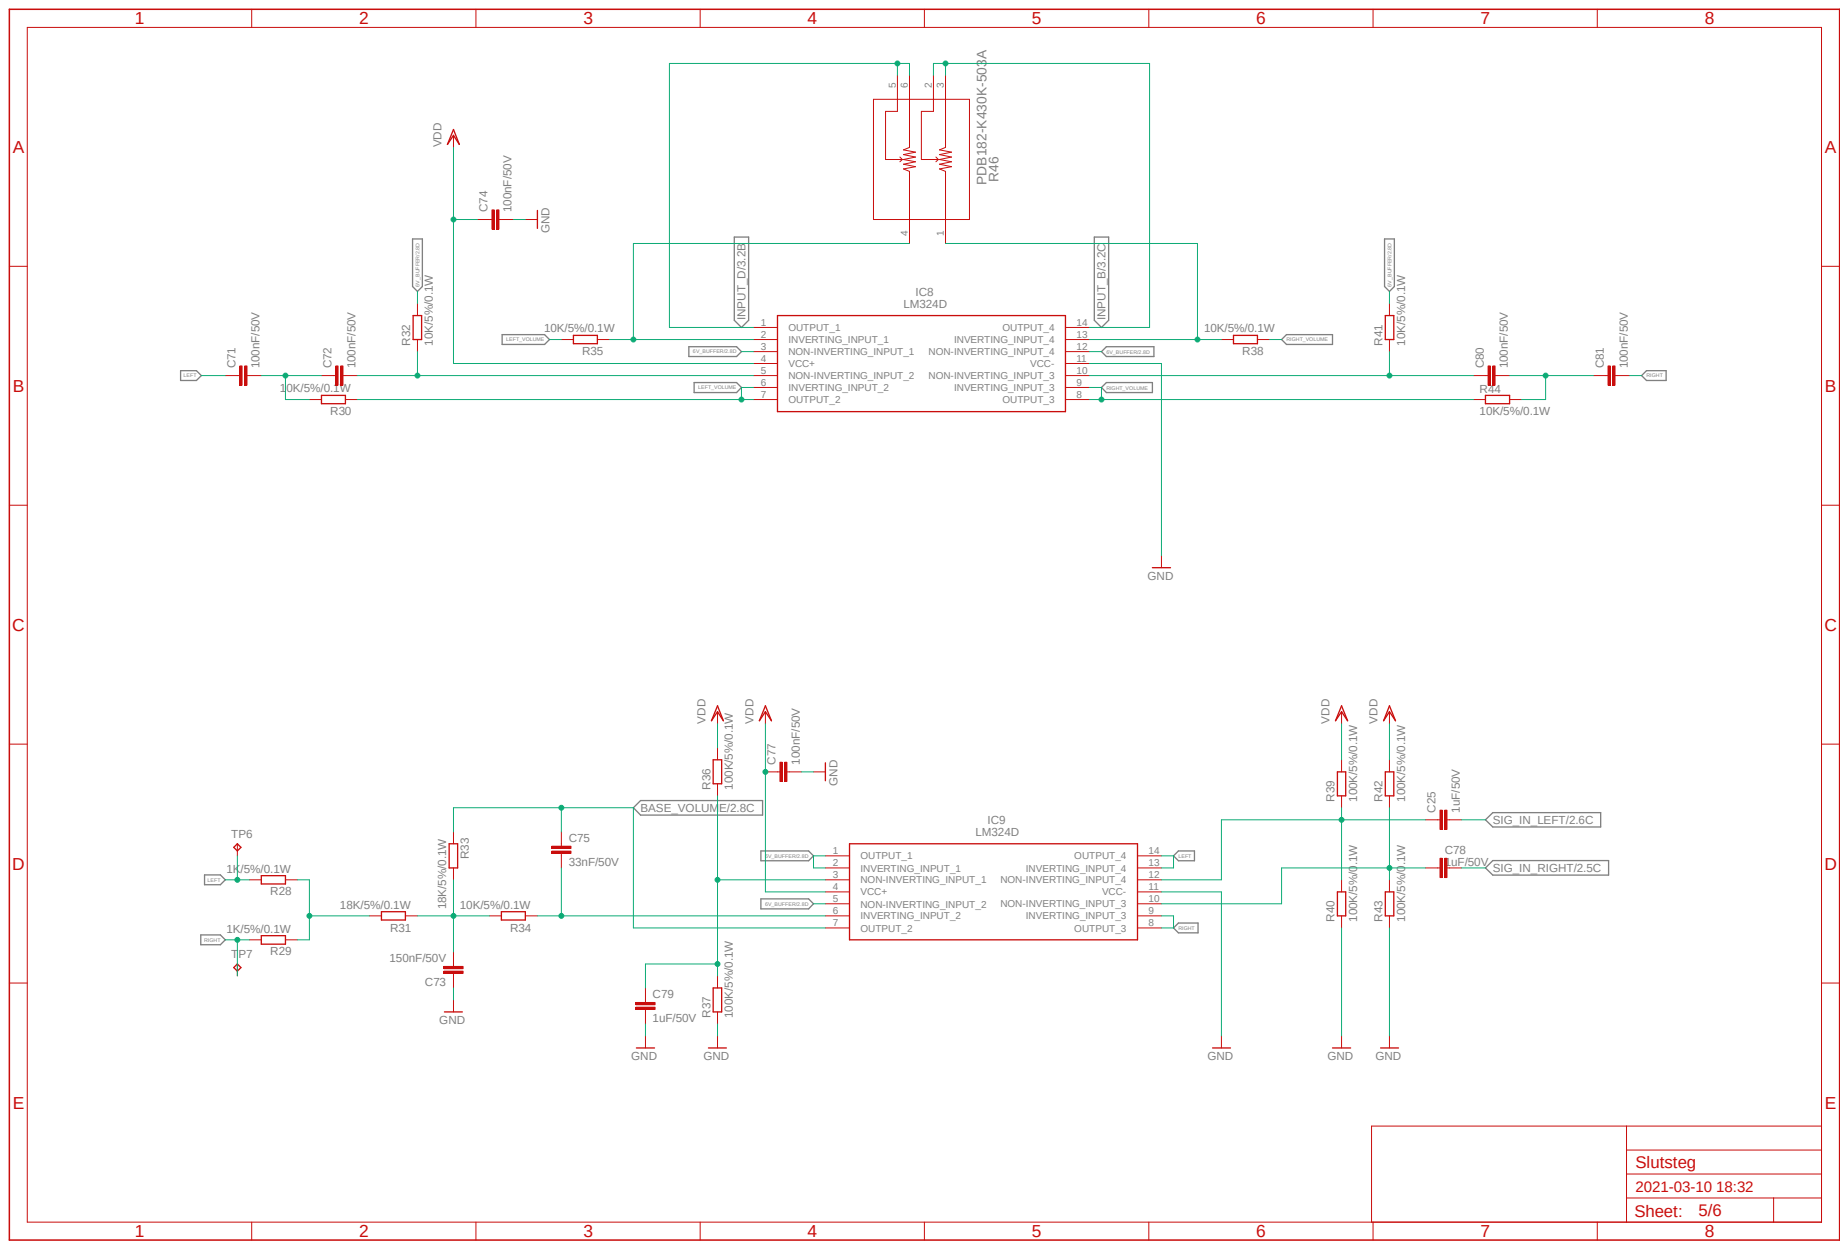
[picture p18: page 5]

A

A

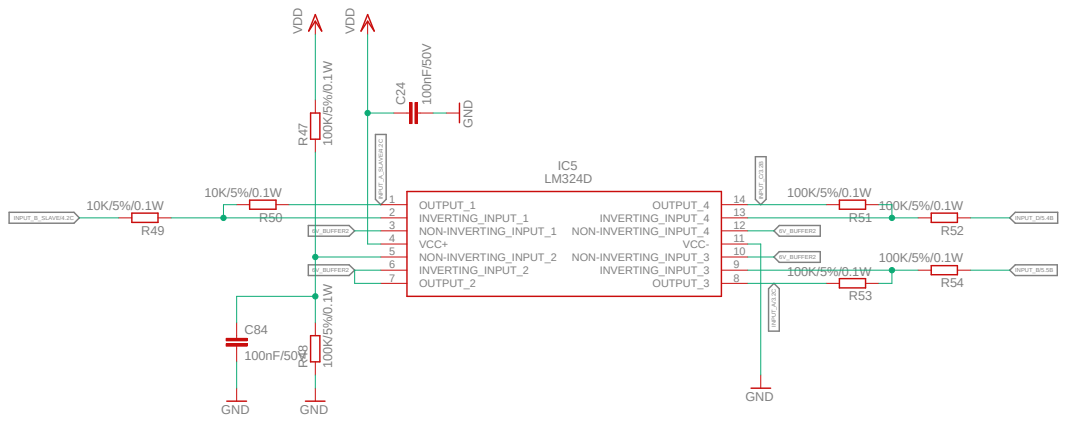
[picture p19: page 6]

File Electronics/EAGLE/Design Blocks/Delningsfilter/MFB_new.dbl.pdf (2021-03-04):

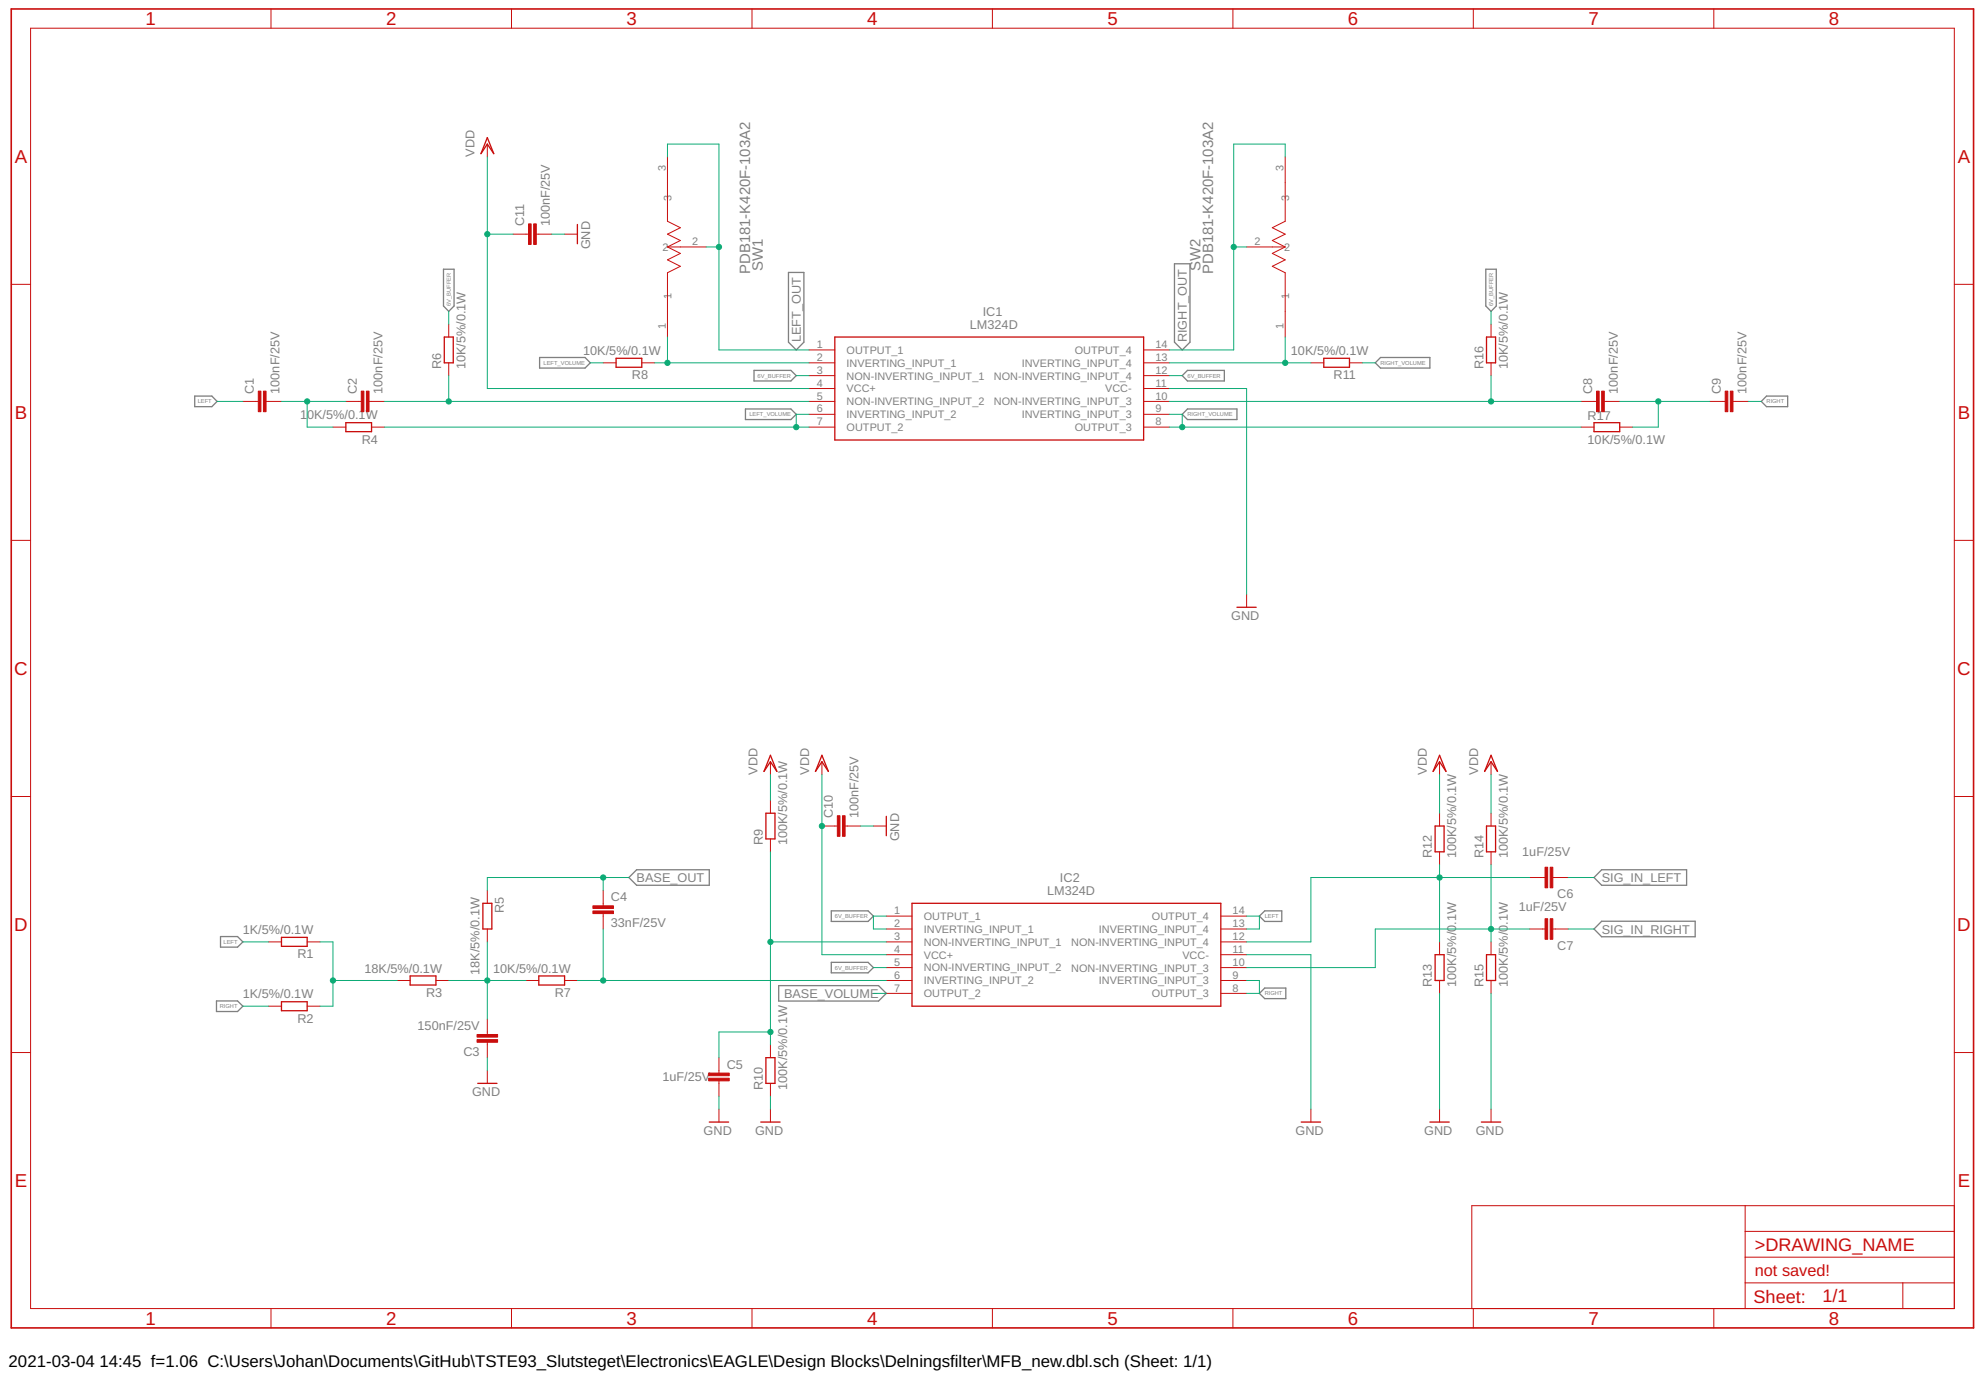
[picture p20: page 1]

2021-03-04 14:45 f=1.06 C:\Users\Johan\Documents\GitHub\TSTE93_Slutsteget\Electronics\EAGLE\Design Blocks\Delningsfilter\MFB_new.dbl.sch (Sheet: 1/1)

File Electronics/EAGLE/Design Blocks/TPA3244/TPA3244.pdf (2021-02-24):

# Master BTL Mode

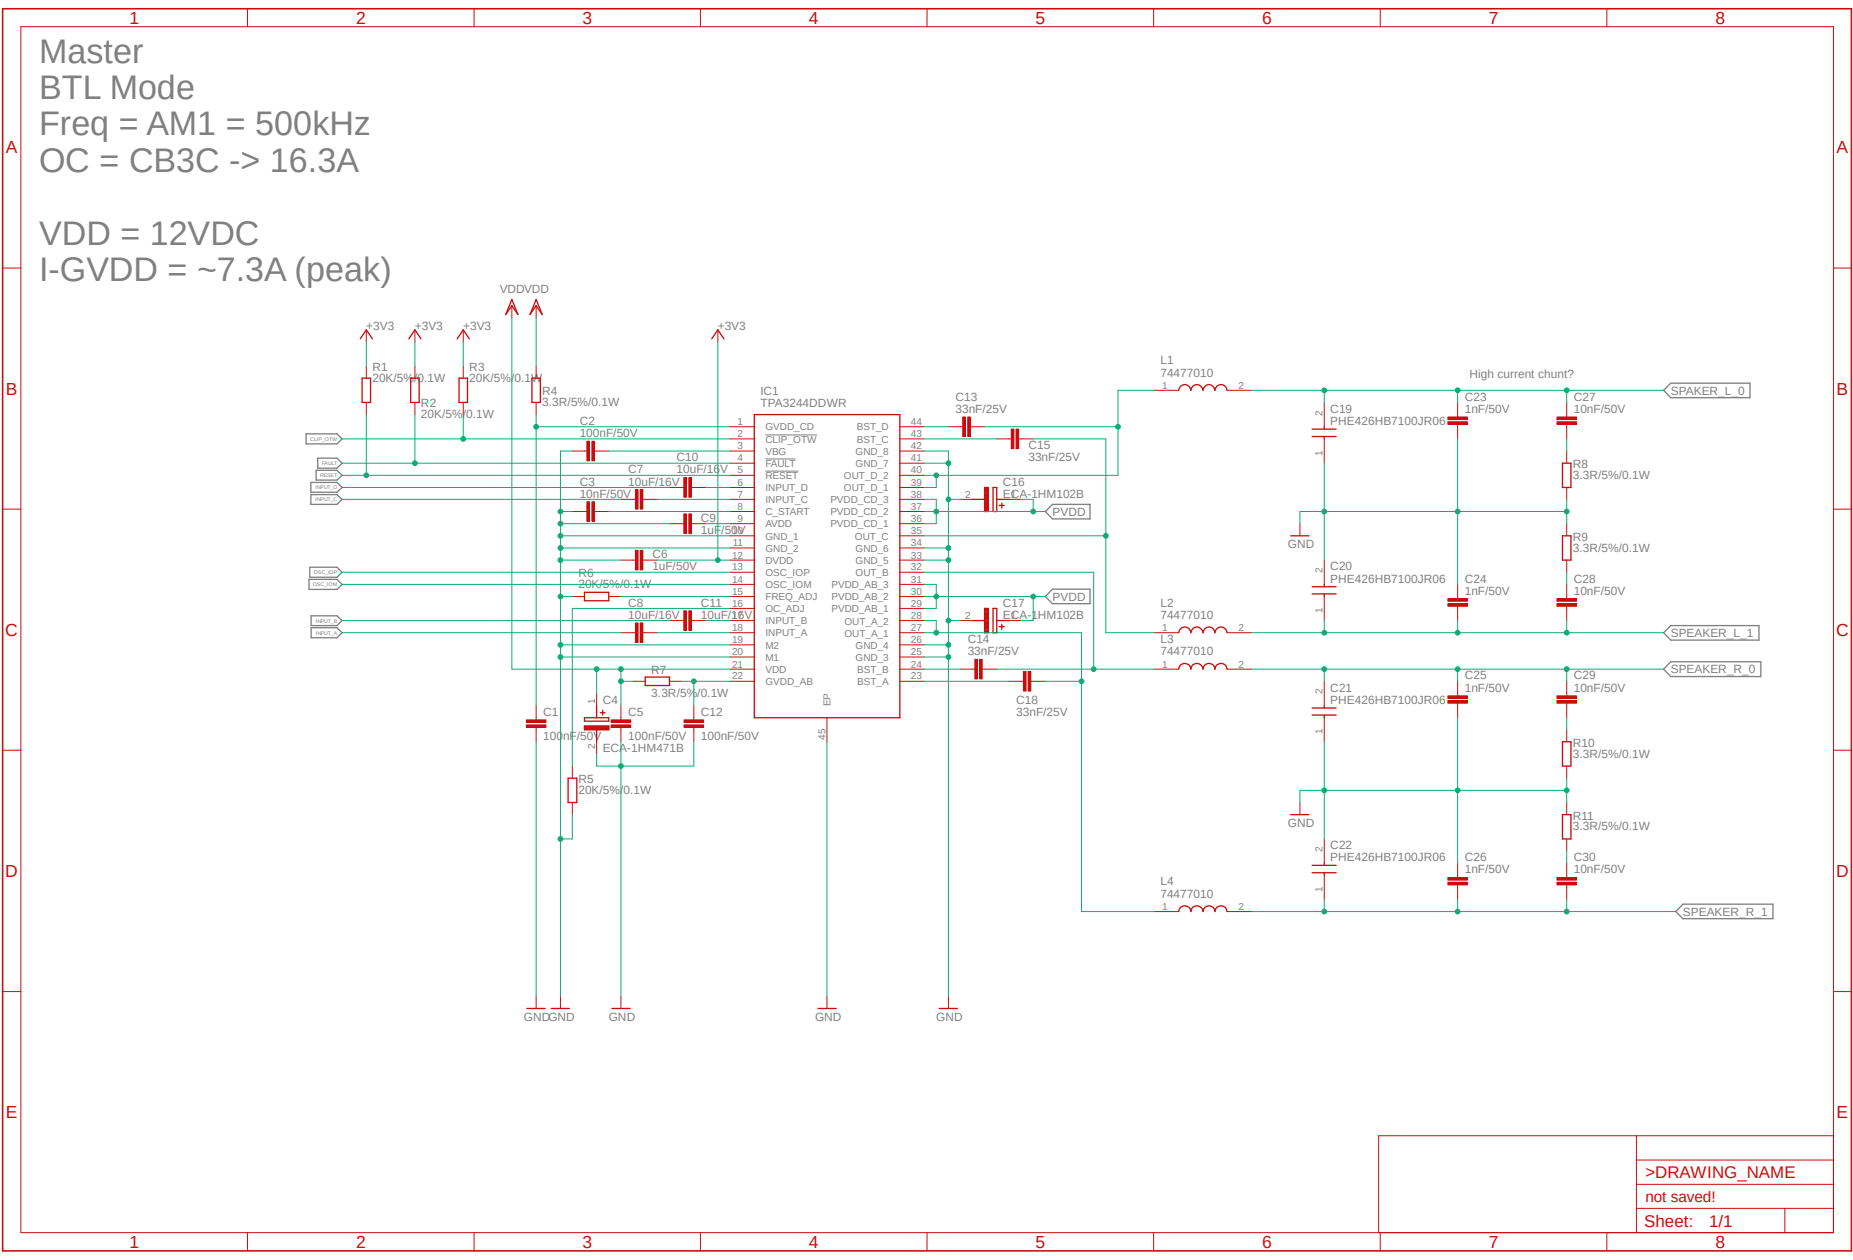
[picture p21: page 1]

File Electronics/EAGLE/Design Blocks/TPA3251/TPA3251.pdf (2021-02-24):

A

A

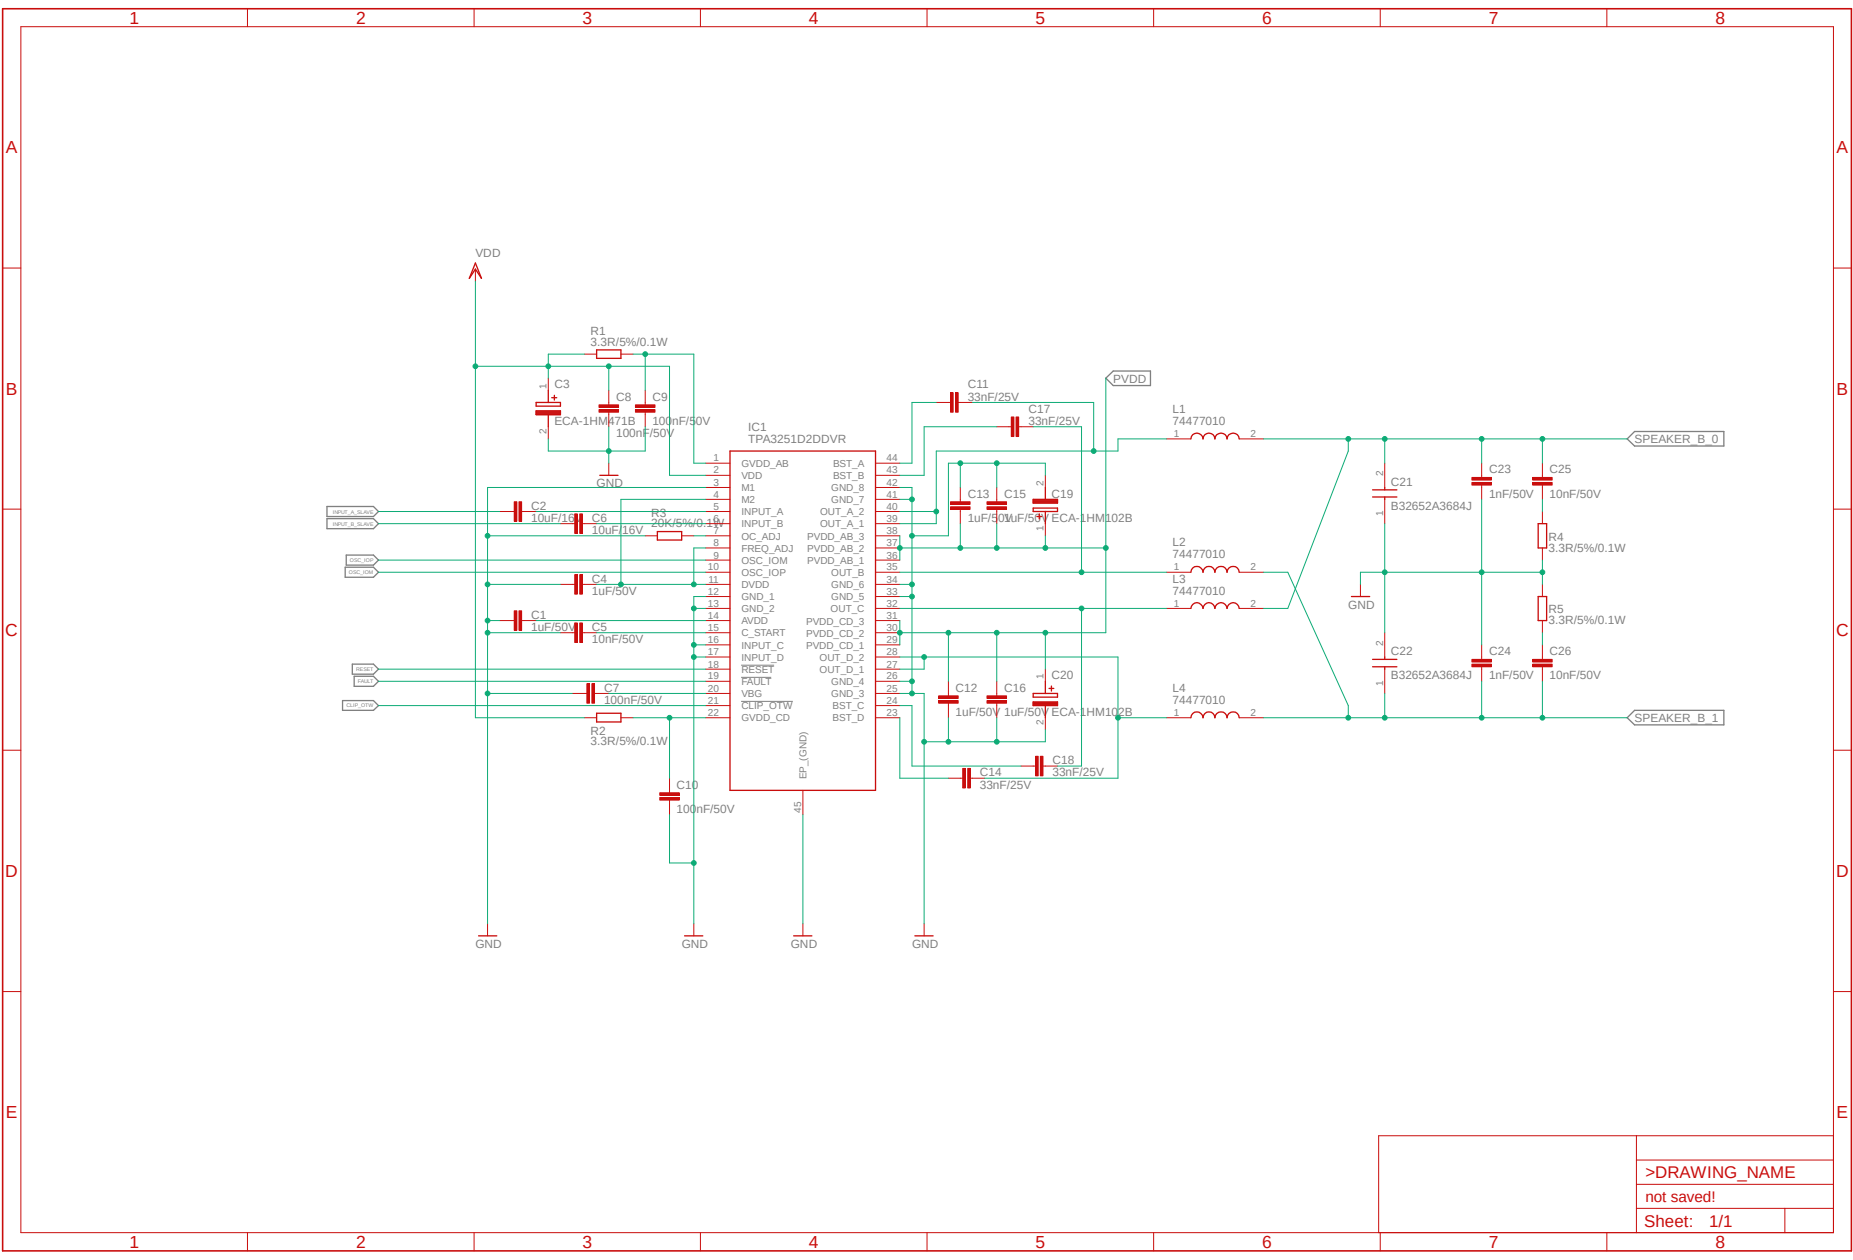
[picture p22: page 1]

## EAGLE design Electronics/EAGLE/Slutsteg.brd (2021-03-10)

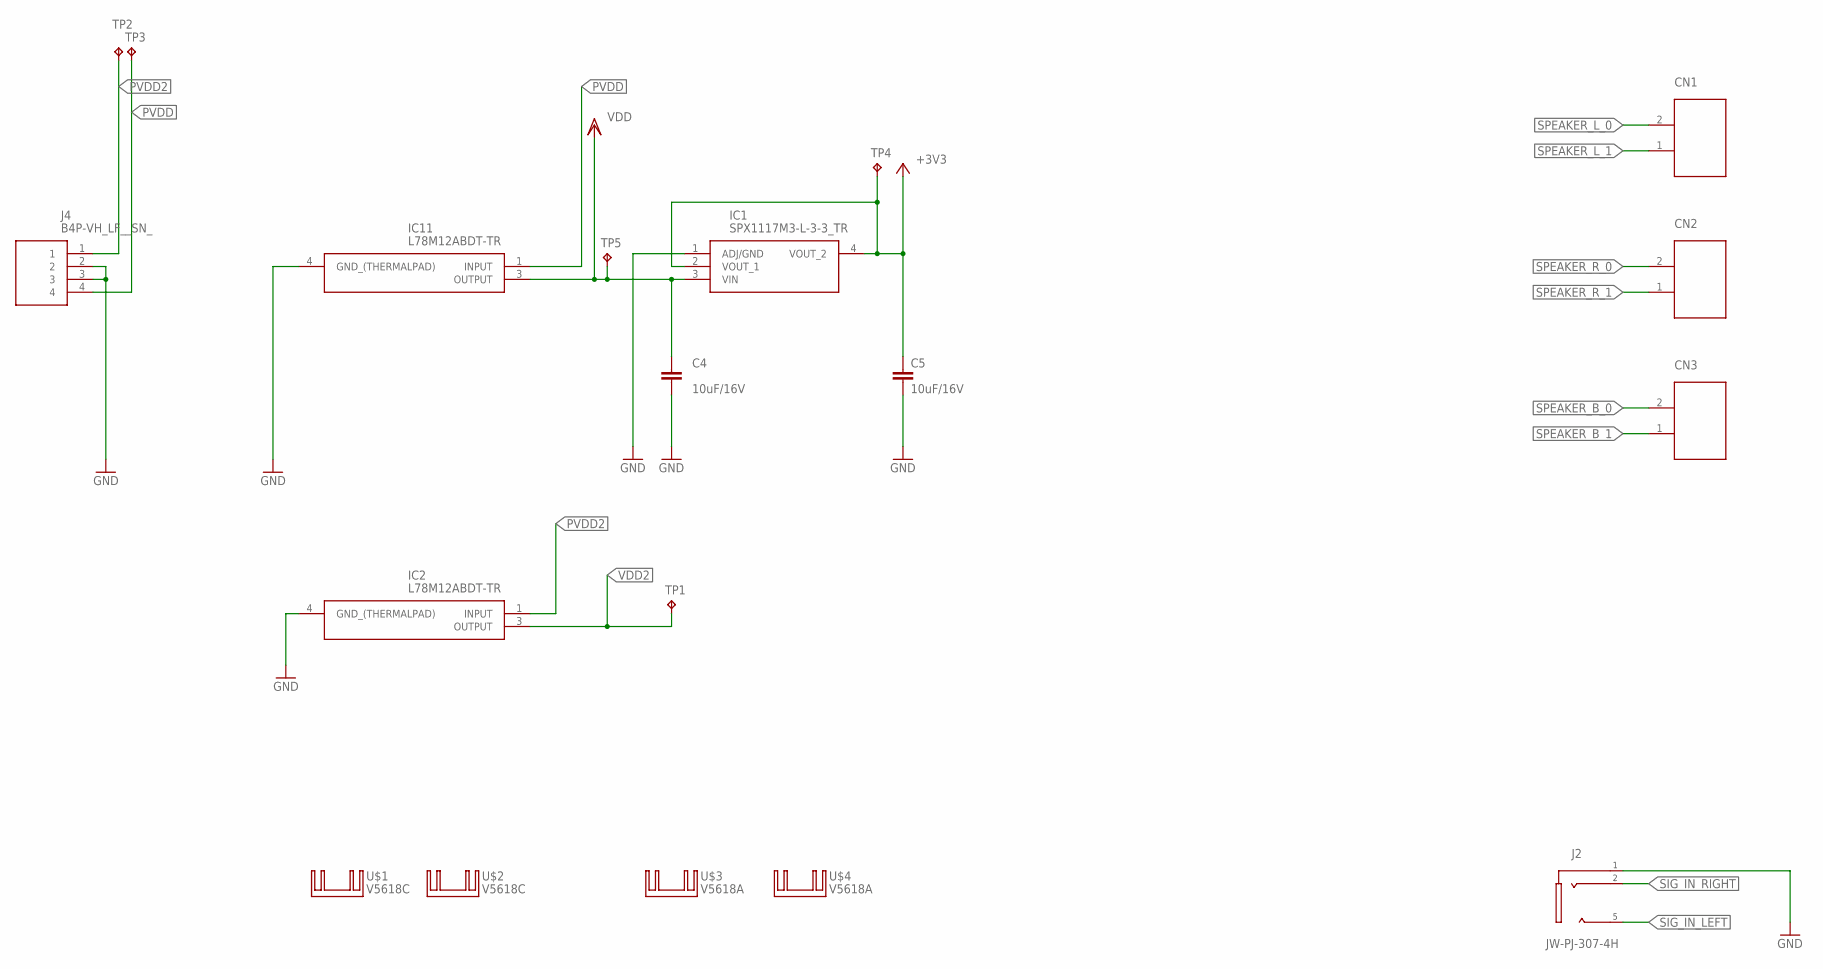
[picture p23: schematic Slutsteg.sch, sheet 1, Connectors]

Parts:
C4, C5: 10uF/16V; C0805
CN1, CN2, CN3: OSTYK33102030-2; OSTYK33108030-2
IC1: SPX1117M3-L-3-3_TR; SOT230P700X180-4N
IC2, IC11: L78M12ABDT-TR; TO228P972X240-3N
J2: JW-PJ-307-4H
J4: B4P-VH_LF__SN_; SHDR4W114P0X396_1X4_1578X850X9
TP1: TPB2,54; B2,54
TP2, TP3, TP4, TP5: TPB1,27; B1,27
U$1, U$2: V5618C
U$3, U$4: V5618A

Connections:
+3V3: C5.1, IC1.2 (VOUT_1), IC1.4 (VOUT_2), TP4.TP; also elsewhere on the board
GND: C4.2, C5.2, IC1.1 (ADJ/GND), IC2.4 (GND_(THERMALPAD)), IC11.4 (GND_(THERMALPAD)), J2.1, J4.2, J4.3; also elsewhere on the board
PVDD: IC11.1 (INPUT), J4.4, TP3.TP; also elsewhere on the board
PVDD2: IC2.1 (INPUT), J4.1, TP2.TP; also elsewhere on the board
SIG_IN_LEFT: J2.5; also elsewhere on the board
SIG_IN_RIGHT: J2.2; also elsewhere on the board
SPEAKER_B_0: CN3.2; also elsewhere on the board
SPEAKER_B_1: CN3.1; also elsewhere on the board
SPEAKER_L_0: CN1.2; also elsewhere on the board
SPEAKER_L_1: CN1.1; also elsewhere on the board
SPEAKER_R_0: CN2.2; also elsewhere on the board
SPEAKER_R_1: CN2.1; also elsewhere on the board
VDD: C4.1, IC1.3 (VIN), IC11.3 (OUTPUT), TP5.TP; also elsewhere on the board
VDD2: IC2.3 (OUTPUT), TP1.TP; also elsewhere on the board

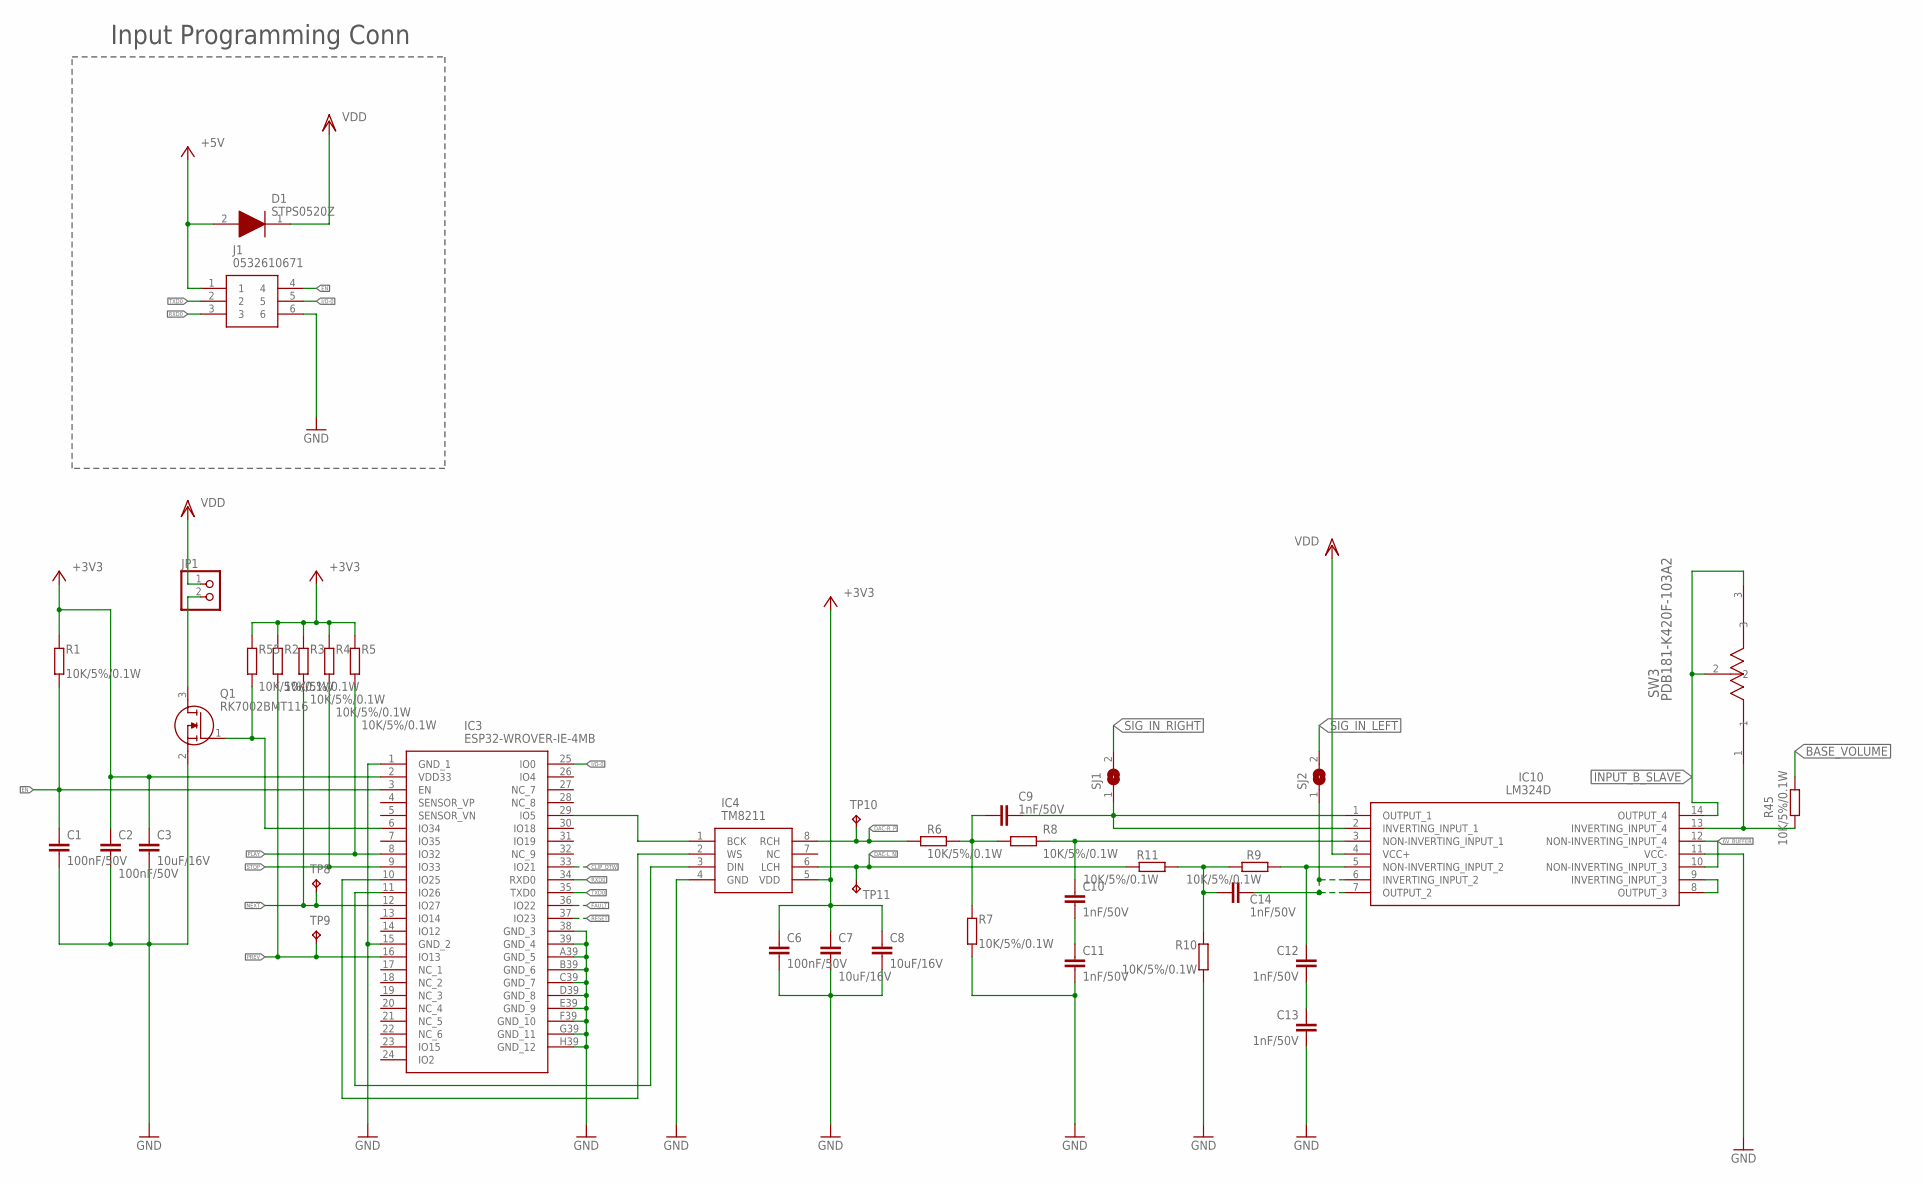
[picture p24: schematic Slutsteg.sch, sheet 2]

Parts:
C1, C2, C6: 100nF/50V; C0603
C3, C7, C8: 10uF/16V; C0805
C9, C10, C11, C12, C13, C14: 1nF/50V; C0603
D1: STPS0520Z; SOD3816X145N
IC3: ESP32-WROVER-IE-4MB; ESP32WROVERE8MB
IC4: TM8211; SOIC127P600X196-8N
IC10: LM324D; SOIC127P600X175-14N
J1: 0532610671
JP1: PINHD-1X2; 1X02
Q1: RK7002BMT116; BSS64AHZGT116
R1, R2, R3, R4, R5, R6, R7, R8, R9, R10, R11, R45, R55: 10K/5%/0.1W; R0603
SJ1, SJ2: SJ
SW3: PDB181-K420F-103A2; SW_420F-103A2_BRN
TP8, TP9, TP10, TP11: TPB1,27; B1,27

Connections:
6V_BUFFER: IC10.10 (NON-INVERTING_INPUT_3), IC10.12 (NON-INVERTING_INPUT_4); also elsewhere on the board
+3V3: C2.1, C3.1, C6.1, C7.1, C8.1, IC3.2 (VDD33), IC4.5 (VDD), R1.1, R2.1, R3.1, R4.1, R5.1, R55.1; also elsewhere on the board
+5V: D1.2 (A), J1.1
BASE_VOLUME: R45.1; also elsewhere on the board
CLIP_OTW: IC3.33 (IO21); also elsewhere on the board
DAC-L_N: IC4.6 (LCH), R11.1, TP11.TP
DAC-R_P: IC4.8 (RCH), R6.2, TP10.TP
EN: C1.1, IC3.3 (EN), J1.4, R1.2
FAULT: IC3.36 (IO22); also elsewhere on the board
GND: C1.2, C2.2, C3.2, C6.2, C7.2, C8.2, C11.2, C13.2, IC3.1 (GND_1), IC3.15 (GND_2), IC3.38 (GND_3), IC3.39 (GND_4), IC3.A39 (GND_5), IC3.B39 (GND_6), IC3.C39 (GND_7), IC3.D39 (GND_8), IC3.E39 (GND_9), IC3.F39 (GND_10), IC3.G39 (GND_11), IC3.H39 (GND_12), IC4.4 (GND), IC10.11 (VCC-), J1.6, Q1.2 (S), R7.2, R10.2; also elsewhere on the board
GSDJT: C9.1, IC10.1 (OUTPUT_1), IC10.2 (INVERTING_INPUT_1), SJ1.1
I/O-0: IC3.25 (IO0), J1.5
INPUT_B_SLAVE: IC10.14 (OUTPUT_4), SW3.2, SW3.3; also elsewhere on the board
unnamed: IC10.13 (INVERTING_INPUT_4), R45.2, SW3.1
unnamed: IC10.8 (OUTPUT_3), IC10.9 (INVERTING_INPUT_3)
unnamed: IC3.6 (IO34), Q1.1 (G), R55.2
unnamed: JP1.2, Q1.3 (D)
unnamed: IC3.11 (IO26), IC4.3 (DIN)
unnamed: IC3.29 (IO5), IC4.1 (BCK)
unnamed: IC3.10 (IO25), IC4.2 (WS)
unnamed: C10.1, IC10.3 (NON-INVERTING_INPUT_1), R8.1
unnamed: C10.2, C11.1
unnamed: C12.1, IC10.5 (NON-INVERTING_INPUT_2), R9.2
unnamed: C12.2, C13.1
unnamed: C14.2, R9.1, R10.1, R11.2
unnamed: C9.2, R6.1, R7.1, R8.2
NEXT: IC3.12 (IO27), R3.2, TP8.TP
PLAY: IC3.8 (IO32), R5.2
PREV: IC3.16 (IO13), R2.2, TP9.TP
RESET: IC3.37 (IO23); also elsewhere on the board
RXD0: IC3.34 (RXD0), J1.3
SIG_IN_LEFT: SJ2.2; also elsewhere on the board
SIG_IN_RIGHT: SJ1.2; also elsewhere on the board
STOP: IC3.9 (IO33), R4.2
TGHJESYRJK: C14.1, IC10.6 (INVERTING_INPUT_2), IC10.7 (OUTPUT_2), SJ2.1
TXD0: IC3.35 (TXD0), J1.2
VDD: D1.1 (K), IC10.4 (VCC+), JP1.1; also elsewhere on the board

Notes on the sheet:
Input Programming Conn

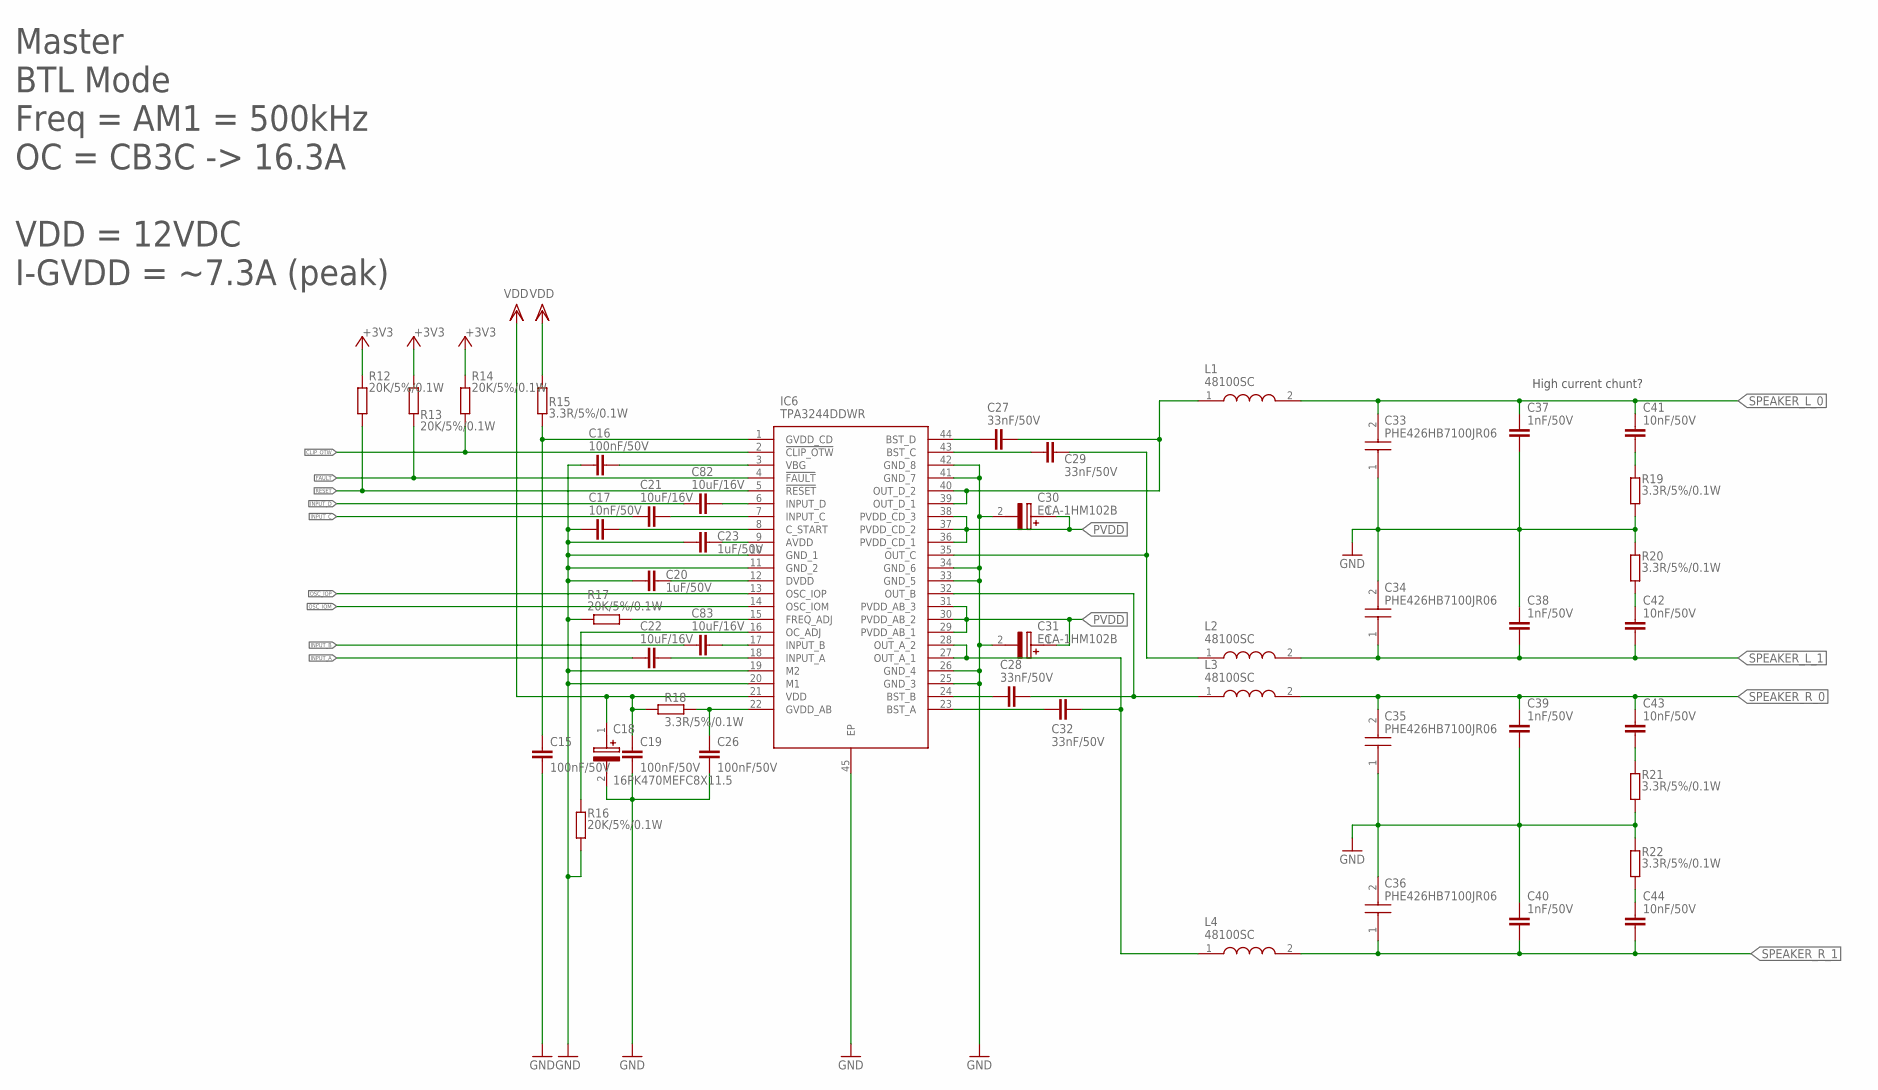
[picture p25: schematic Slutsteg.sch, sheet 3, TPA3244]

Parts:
C15, C16, C19, C26: 100nF/50V; C0603
C17, C41, C42, C43, C44: 10nF/50V; C0603
C18: 16PK470MEFC8X11.5; CAPPRD350W60D825H1300
C20, C23: 1uF/50V; C0805
C21, C22, C82, C83: 10uF/16V; C0805
C27, C28, C29, C32: 33nF/50V; C0603
C30, C31: ECA-1HM102B; CAPPRD500W60D1300H2650
C33, C34, C35, C36: PHE426HB7100JR06
C37, C38, C39, C40: 1nF/50V; C0603
IC6: TPA3244DDWR; SOP64P810X120-45N
L1, L2, L3, L4: 48100SC; INDPM122122X600N
R12, R13, R14, R16, R17: 20K/5%/0.1W; R0603
R15, R18, R19, R20, R21, R22: 3.3R/5%/0.1W; R0603

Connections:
+3V3: R12.2, R13.2, R14.2; also elsewhere on the board
CLIP_OTW: IC6.2 (!CLIP_OTW), R14.1; also elsewhere on the board
FAULT: IC6.4 (!FAULT), R13.1; also elsewhere on the board
GND: C15.2, C16.2, C17.2, C18.2 (-), C19.2, C20.1, C23.1, C26.2, C30.2 (-), C31.2 (-), C33.1, C34.2, C35.1, C36.2, C37.2, C38.1, C39.2, C40.1, IC6.10 (GND_1), IC6.11 (GND_2), IC6.19 (M2), IC6.20 (M1), IC6.25 (GND_3), IC6.26 (GND_4), IC6.33 (GND_5), IC6.34 (GND_6), IC6.41 (GND_7), IC6.42 (GND_8), IC6.45 (EP), R16.1, R17.1, R19.1, R20.2, R21.1, R22.2; also elsewhere on the board
INPUT_A: C22.1; also elsewhere on the board
INPUT_B: C83.1; also elsewhere on the board
INPUT_C: C21.1; also elsewhere on the board
INPUT_D: C82.1; also elsewhere on the board
unnamed: C20.2, IC6.12 (DVDD)
unnamed: C82.2, IC6.6 (INPUT_D)
unnamed: C83.2, IC6.17 (INPUT_B)
unnamed: C27.1, IC6.44 (BST_D)
unnamed: C29.1, IC6.43 (BST_C)
unnamed: C41.2, R19.2
unnamed: C42.1, R20.1
unnamed: C28.1, IC6.24 (BST_B)
unnamed: C32.1, IC6.23 (BST_A)
unnamed: C43.2, R21.2
unnamed: C44.1, R22.1
unnamed: IC6.15 (FREQ_ADJ), R17.2
unnamed: C16.1, IC6.3 (VBG)
unnamed: C17.1, IC6.8 (C_START)
unnamed: C23.2, IC6.9 (AVDD)
unnamed: C15.1, IC6.1 (GVDD_CD), R15.1
unnamed: C26.1, IC6.22 (GVDD_AB), R18.1
unnamed: C21.2, IC6.7 (INPUT_C)
unnamed: C22.2, IC6.18 (INPUT_A)
unnamed: IC6.16 (OC_ADJ), R16.2
OSC_IOM: IC6.14 (OSC_IOM); also elsewhere on the board
OSC_IOP: IC6.13 (OSC_IOP); also elsewhere on the board
OUT_A: C32.2, IC6.27 (OUT_A_1), IC6.28 (OUT_A_2), L4.1
OUT_B: C28.2, IC6.32 (OUT_B), L3.1
OUT_C: C29.2, IC6.35 (OUT_C), L2.1
OUT_D: C27.2, IC6.39 (OUT_D_1), IC6.40 (OUT_D_2), L1.1
PVDD: C30.1 (+), C31.1 (+), IC6.29 (PVDD_AB_1), IC6.30 (PVDD_AB_2), IC6.31 (PVDD_AB_3), IC6.36 (PVDD_CD_1), IC6.37 (PVDD_CD_2), IC6.38 (PVDD_CD_3); also elsewhere on the board
RESET: IC6.5 (!RESET), R12.1; also elsewhere on the board
SPEAKER_L_0: C33.2, C37.1, C41.1, L1.2; also elsewhere on the board
SPEAKER_L_1: C34.1, C38.2, C42.2, L2.2; also elsewhere on the board
SPEAKER_R_0: C35.2, C39.1, C43.1, L3.2; also elsewhere on the board
SPEAKER_R_1: C36.1, C40.2, C44.2, L4.2; also elsewhere on the board
VDD: C18.1 (+), C19.1, IC6.21 (VDD), R15.2, R18.2; also elsewhere on the board

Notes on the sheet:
High current chunt?
Master BTL Mode Freq = AM1 = 500kHz OC = CB3C -> 16.3A VDD = 12VDC I-GVDD = ~7.3A (peak)

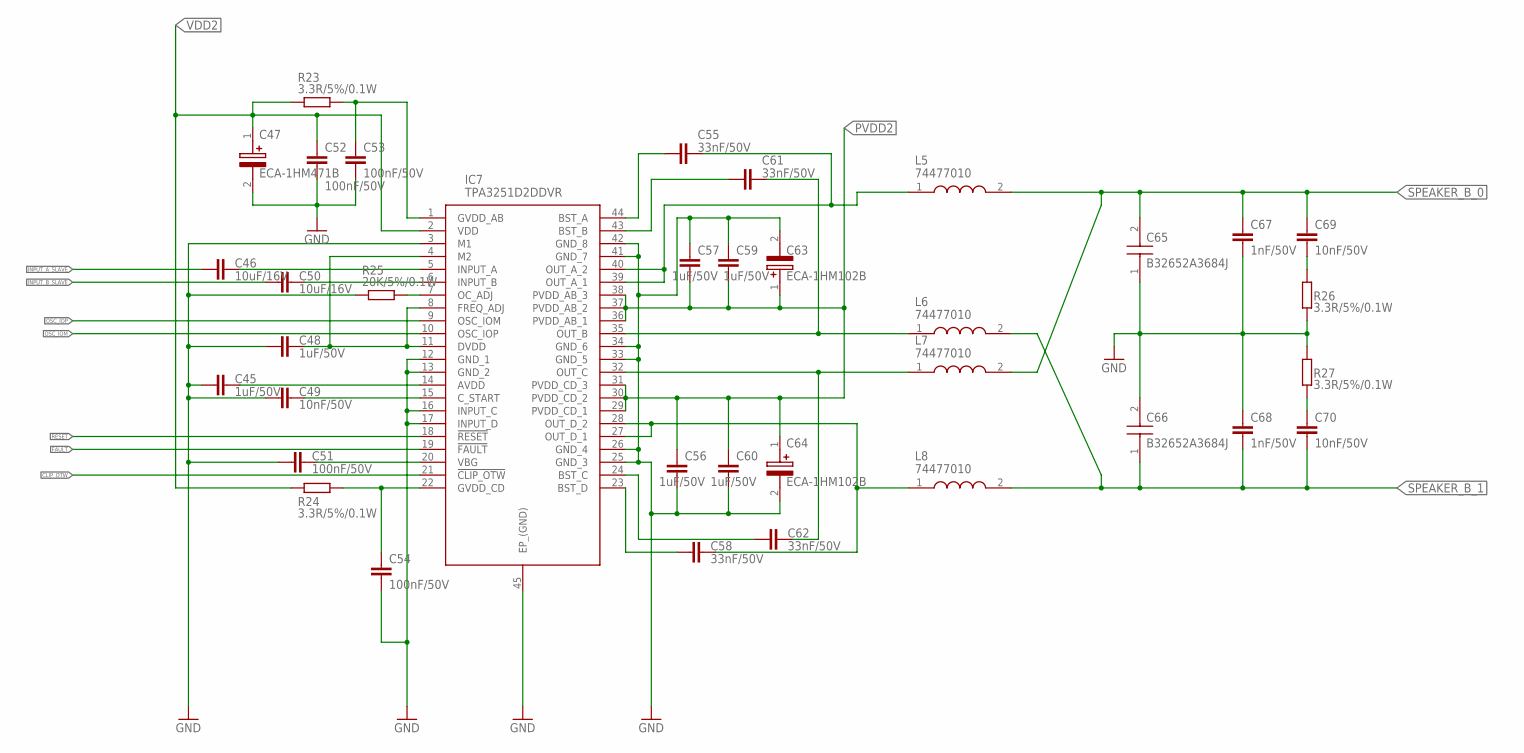
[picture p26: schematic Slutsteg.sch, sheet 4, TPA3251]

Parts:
C45, C48, C56, C57, C59, C60: 1uF/50V; C0805
C46, C50: 10uF/16V; C0805
C47: ECA-1HM471B; CAPPRD350W60D825H1300
C49, C69, C70: 10nF/50V; C0603
C51, C52, C53, C54: 100nF/50V; C0603
C55, C58, C61, C62: 33nF/50V; C0603
C63, C64: ECA-1HM102B; CAPPRD500W60D1300H2650
C65, C66: B32652A3684J
C67, C68: 1nF/50V; C0603
IC7: TPA3251D2DDVR; SOP64P810X120-45N@1
L5, L6, L7, L8: 74477010; WE-PD_1260/1245/1280/121054
R23, R24, R26, R27: 3.3R/5%/0.1W; R0603
R25: 20K/5%/0.1W; R0603

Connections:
CLIP_OTW: IC7.21 (!CLIP_OTW); also elsewhere on the board
FAULT: IC7.19 (!FAULT); also elsewhere on the board
GND: C45.1, C47.2 (-), C48.1, C49.1, C51.1, C52.2, C53.2, C54.2, C56.2, C57.1, C59.1, C60.2, C63.2 (-), C64.2 (-), C65.1, C66.2, C67.2, C68.1, IC7.3 (M1), IC7.12 (GND_1), IC7.13 (GND_2), IC7.16 (INPUT_C), IC7.17 (INPUT_D), IC7.25 (GND_3), IC7.26 (GND_4), IC7.33 (GND_5), IC7.34 (GND_6), IC7.41 (GND_7), IC7.42 (GND_8), IC7.45 (EP_(GND)), R25.1, R26.1, R27.2; also elsewhere on the board
INPUT_A_SLAVE: C46.2; also elsewhere on the board
INPUT_B_SLAVE: C50.2; also elsewhere on the board
unnamed: C70.1, R27.1
unnamed: C55.1, IC7.44 (BST_A)
unnamed: C55.2, IC7.39 (OUT_A_1), IC7.40 (OUT_A_2), L5.1
unnamed: C61.2, IC7.35 (OUT_B), L6.1
unnamed: C58.1, IC7.23 (BST_D)
unnamed: C62.1, IC7.24 (BST_C)
unnamed: C62.2, IC7.32 (OUT_C), L7.1
unnamed: C46.1, IC7.5 (INPUT_A)
unnamed: C50.1, IC7.6 (INPUT_B)
unnamed: C53.1, IC7.1 (GVDD_AB), R23.2
unnamed: C51.2, IC7.20 (VBG)
unnamed: C49.2, IC7.15 (C_START)
unnamed: C45.2, IC7.14 (AVDD)
unnamed: C48.2, IC7.4 (M2), IC7.8 (FREQ_ADJ), IC7.11 (DVDD)
unnamed: IC7.7 (OC_ADJ), R25.2
unnamed: C61.1, IC7.43 (BST_B)
unnamed: C58.2, IC7.27 (OUT_D_1), IC7.28 (OUT_D_2), L8.1
unnamed: C54.1, IC7.22 (GVDD_CD), R24.2
unnamed: C69.2, R26.2
OSC_IOM: IC7.10 (OSC_IOP); also elsewhere on the board
OSC_IOP: IC7.9 (OSC_IOM); also elsewhere on the board
PVDD2: C56.1, C57.2, C59.2, C60.1, C63.1 (+), C64.1 (+), IC7.29 (PVDD_CD_1), IC7.30 (PVDD_CD_2), IC7.31 (PVDD_CD_3), IC7.36 (PVDD_AB_1), IC7.37 (PVDD_AB_2), IC7.38 (PVDD_AB_3); also elsewhere on the board
RESET: IC7.18 (!RESET); also elsewhere on the board
SPEAKER_B_0: C65.2, C67.1, C69.1, L5.2, L7.2; also elsewhere on the board
SPEAKER_B_1: C66.1, C68.2, C70.2, L6.2, L8.2; also elsewhere on the board
VDD2: C47.1 (+), C52.1, IC7.2 (VDD), R23.1, R24.1; also elsewhere on the board

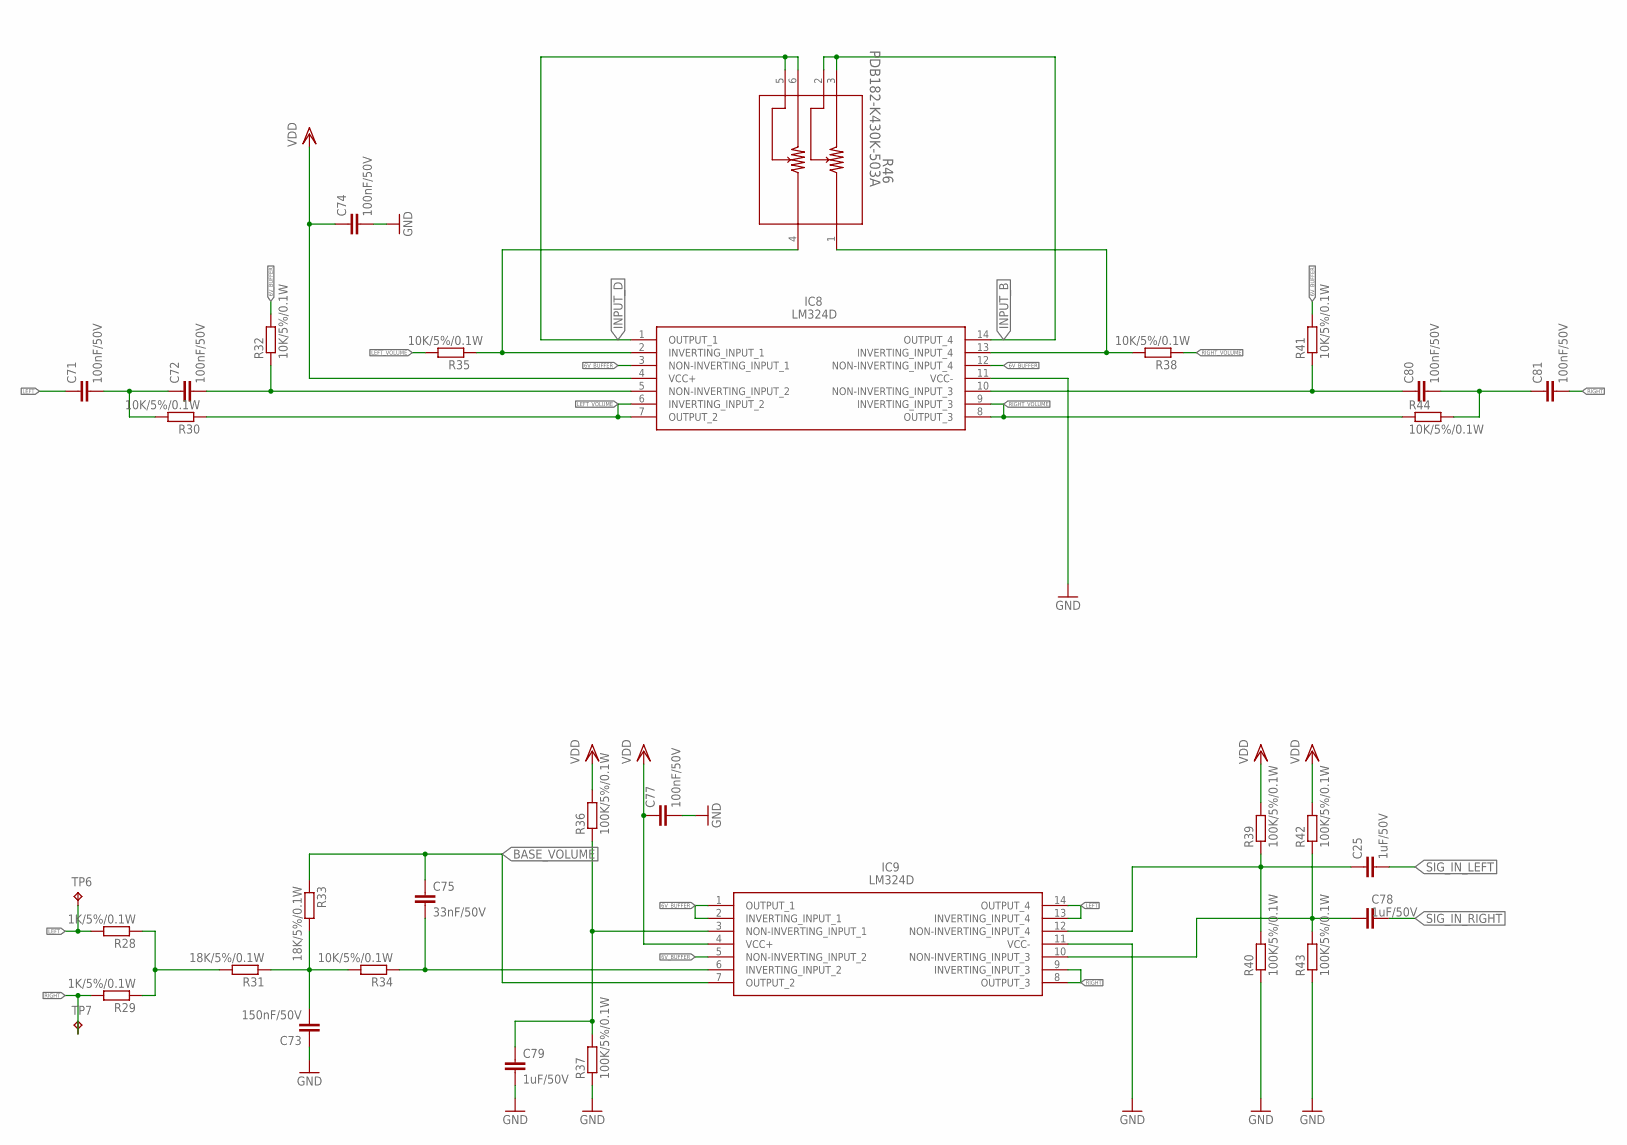
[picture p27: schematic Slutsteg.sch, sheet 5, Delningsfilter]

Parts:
C25, C78, C79: 1uF/50V; C0805
C71, C72, C74, C77, C80, C81: 100nF/50V; C0603
C73: 150nF/50V; C0603
C75: 33nF/50V; C0603
IC8, IC9: LM324D; SOIC127P600X175-14N
R28, R29: 1K/5%/0.1W; R0603
R30, R32, R34, R35, R38, R41, R44: 10K/5%/0.1W; R0603
R31, R33: 18K/5%/0.1W; R0603
R36, R37, R39, R40, R42, R43: 100K/5%/0.1W; R0603
R46: PDB182-K430K-503A; PDB18-2
TP6, TP7: TPB1,27; B1,27

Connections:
6V_BUFFER: IC8.3 (NON-INVERTING_INPUT_1), IC8.12 (NON-INVERTING_INPUT_4), IC9.1 (OUTPUT_1), IC9.2 (INVERTING_INPUT_1), IC9.5 (NON-INVERTING_INPUT_2), R32.2, R41.2; also elsewhere on the board
BASE_VOLUME: C75.1, IC9.7 (OUTPUT_2), R33.1; also elsewhere on the board
GND: C73.1, C74.2, C77.2, C79.2, IC8.11 (VCC-), IC9.11 (VCC-), R37.1, R40.1, R43.1; also elsewhere on the board
INPUT_B: IC8.14 (OUTPUT_4), R46.2, R46.3; also elsewhere on the board
INPUT_D: IC8.1 (OUTPUT_1), R46.5, R46.6; also elsewhere on the board
LEFT: C71.1, IC9.13 (INVERTING_INPUT_4), IC9.14 (OUTPUT_4), R28.2, TP6.TP
LEFT_VOLUME: IC8.6 (INVERTING_INPUT_2), IC8.7 (OUTPUT_2), R30.1, R35.2
unnamed: C25.1, IC9.12 (NON-INVERTING_INPUT_4), R39.1, R40.2
unnamed: C78.1, IC9.10 (NON-INVERTING_INPUT_3), R42.1, R43.2
unnamed: C79.1, IC9.3 (NON-INVERTING_INPUT_1), R36.1, R37.2
unnamed: R28.1, R29.1, R31.2
unnamed: C73.2, R31.1, R33.2, R34.2
unnamed: C75.2, IC9.6 (INVERTING_INPUT_2), R34.1
unnamed: C71.2, C72.1, R30.2
unnamed: C72.2, IC8.5 (NON-INVERTING_INPUT_2), R32.1
unnamed: IC8.2 (INVERTING_INPUT_1), R35.1, R46.4
unnamed: C80.1, IC8.10 (NON-INVERTING_INPUT_3), R41.1
unnamed: C80.2, C81.1, R44.2
unnamed: IC8.13 (INVERTING_INPUT_4), R38.2, R46.1
RIGHT: C81.2, IC9.8 (OUTPUT_3), IC9.9 (INVERTING_INPUT_3), R29.2, TP7.TP
RIGHT_VOLUME: IC8.8 (OUTPUT_3), IC8.9 (INVERTING_INPUT_3), R38.1, R44.1
SIG_IN_LEFT: C25.2; also elsewhere on the board
SIG_IN_RIGHT: C78.2; also elsewhere on the board
VDD: C74.1, C77.1, IC8.4 (VCC+), IC9.4 (VCC+), R36.2, R39.2, R42.2; also elsewhere on the board

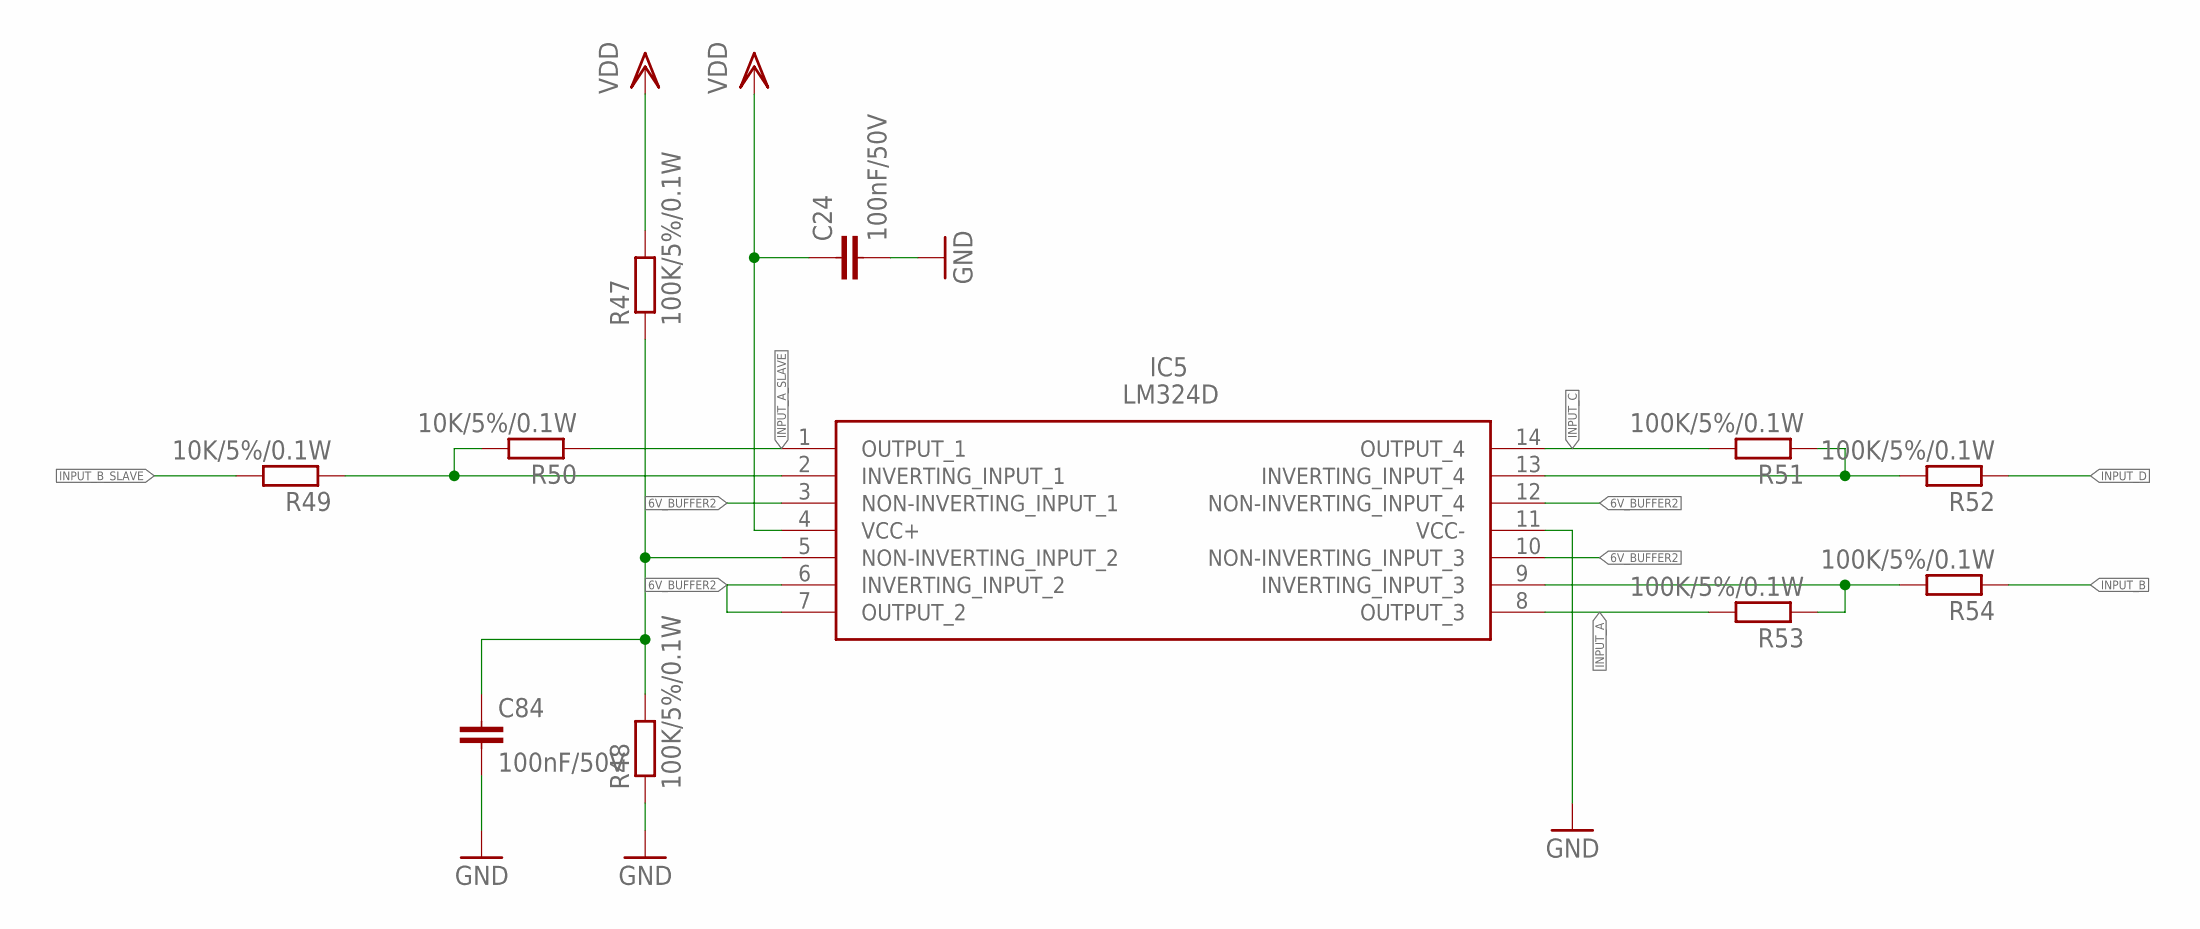
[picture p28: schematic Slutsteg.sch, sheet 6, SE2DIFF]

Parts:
C24, C84: 100nF/50V; C0603
IC5: LM324D; SOIC127P600X175-14N
R47, R48, R51, R52, R53, R54: 100K/5%/0.1W; R0603
R49, R50: 10K/5%/0.1W; R0603

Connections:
6V_BUFFER2: IC5.3 (NON-INVERTING_INPUT_1), IC5.6 (INVERTING_INPUT_2), IC5.7 (OUTPUT_2), IC5.10 (NON-INVERTING_INPUT_3), IC5.12 (NON-INVERTING_INPUT_4)
GND: C24.2, C84.2, IC5.11 (VCC-), R48.1; also elsewhere on the board
INPUT_A: IC5.8 (OUTPUT_3), R53.2; also elsewhere on the board
INPUT_A_SLAVE: IC5.1 (OUTPUT_1), R50.1; also elsewhere on the board
INPUT_B: R54.1; also elsewhere on the board
INPUT_B_SLAVE: R49.2; also elsewhere on the board
INPUT_C: IC5.14 (OUTPUT_4), R51.2; also elsewhere on the board
INPUT_D: R52.1; also elsewhere on the board
unnamed: C84.1, IC5.5 (NON-INVERTING_INPUT_2), R47.1, R48.2
unnamed: IC5.13 (INVERTING_INPUT_4), R51.1, R52.2
unnamed: IC5.2 (INVERTING_INPUT_1), R49.1, R50.2
unnamed: IC5.9 (INVERTING_INPUT_3), R53.1, R54.2
VDD: C24.1, IC5.4 (VCC+), R47.2; also elsewhere on the board

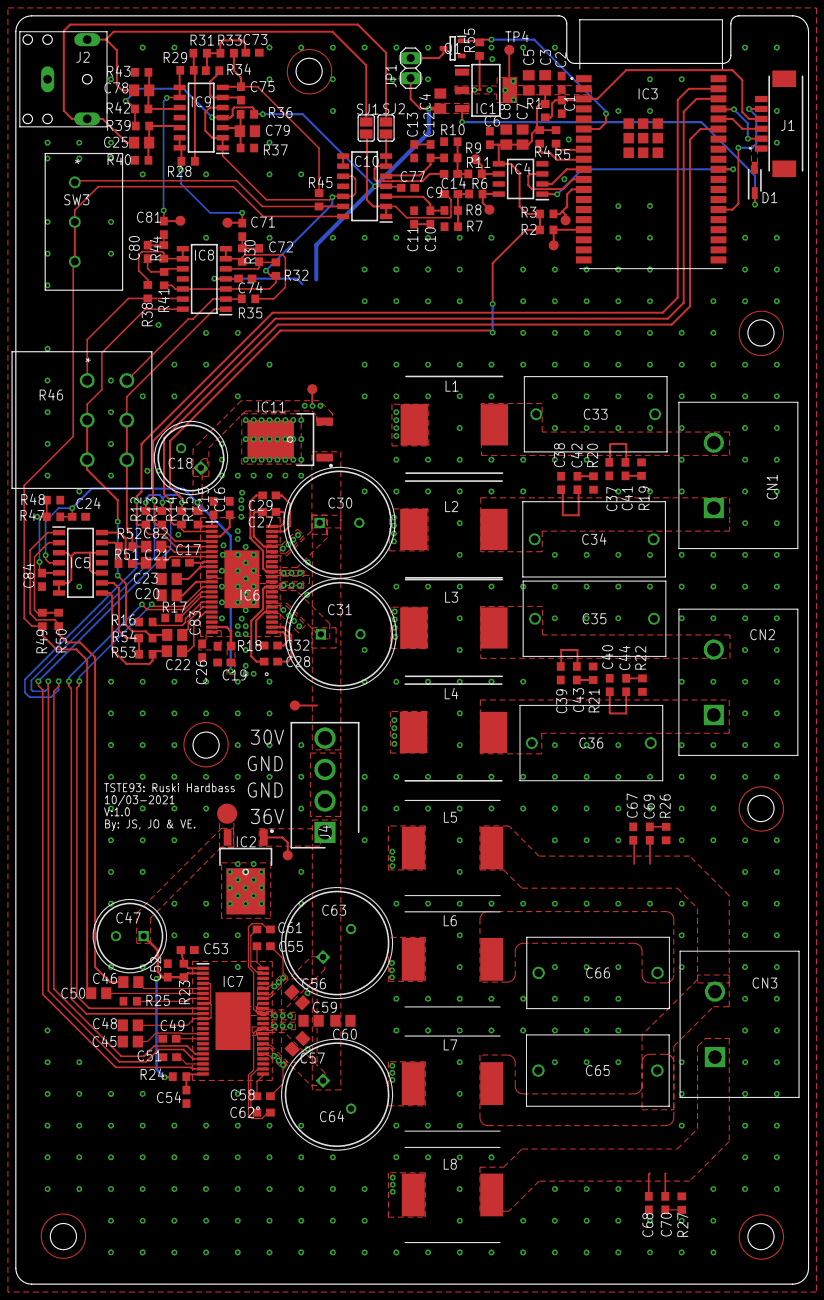
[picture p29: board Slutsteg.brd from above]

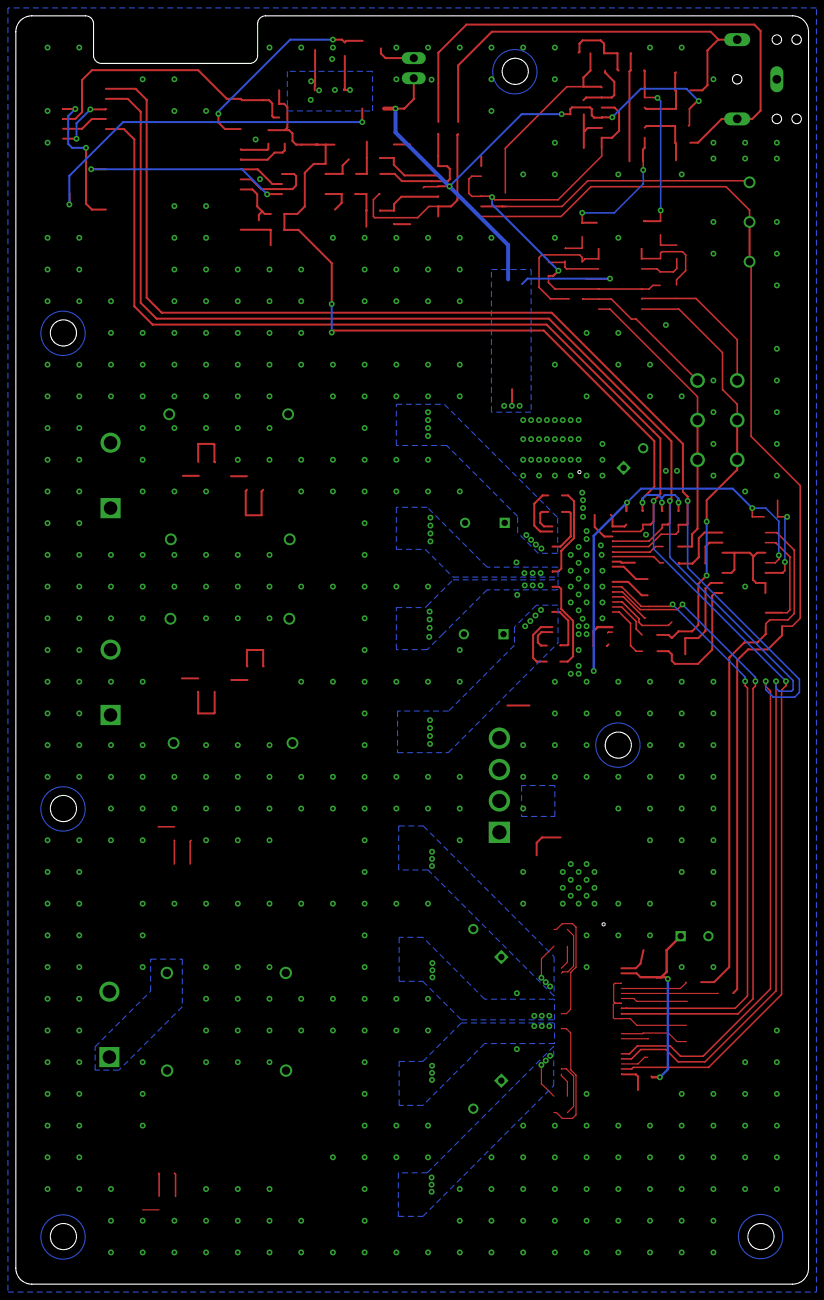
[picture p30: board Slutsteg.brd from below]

Board: 2 copper layers, 100.0 x 160.0 mm, 184 parts (2 on the bottom side), 117 nets.

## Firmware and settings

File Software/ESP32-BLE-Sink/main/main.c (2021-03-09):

/* Play music from Bluetooth device

   This example code is in the Public Domain (or CC0 licensed, at your option.)

   Unless required by applicable law or agreed to in writing, this
   software is distributed on an "AS IS" BASIS, WITHOUT WARRANTIES OR
   CONDITIONS OF ANY KIND, either express or implied.
*/
#include <string.h>
#include "freertos/FreeRTOS.h"
#include "freertos/task.h"
#include "esp_log.h"
#include "nvs_flash.h"
#include "audio_element.h"
#include "audio_pipeline.h"
#include "audio_event_iface.h"
#include "audio_common.h"
#include "i2s_stream.h"
#include "esp_peripherals.h"
#include "periph_touch.h"
#include "periph_adc_button.h"
#include "periph_button.h"
#include "filter_resample.h"
#include "audio_mem.h"
#include "bluetooth_service.h"


static const char *TAG = "BLE Sink";


void app_main(void){

    esp_log_level_set("*", ESP_LOG_INFO);
    esp_log_level_set(TAG, ESP_LOG_DEBUG);


    audio_pipeline_handle_t pipeline;
    audio_element_handle_t bt_stream_reader, i2s_stream_writer;

    nvs_flash_init();

// ******************************************************************
    ESP_LOGI(TAG, "Create Bluetooth service");

    bluetooth_service_cfg_t bt_cfg = {
        .device_name = "OwO BLE Spwekewr",
        .mode = BLUETOOTH_A2DP_SINK,
    };
    bluetooth_service_start(&bt_cfg);


// ******************************************************************
    
    ESP_LOGI(TAG, "Create audio pipeline for playback");

    audio_pipeline_cfg_t pipeline_cfg = DEFAULT_AUDIO_PIPELINE_CONFIG();
    pipeline = audio_pipeline_init(&pipeline_cfg);    


// ******************************************************************

    ESP_LOGI(TAG, "Create i2s stream to write data to codec chip");
    
    i2s_stream_cfg_t i2s_cfg = I2S_STREAM_CFG_DEFAULT();
    i2s_cfg.type = AUDIO_STREAM_WRITER;
    i2s_stream_writer = i2s_stream_init(&i2s_cfg);


    ESP_LOGI(TAG, "Get Bluetooth stream");
    bt_stream_reader = bluetooth_service_create_stream();

    ESP_LOGI(TAG, "Register all elements to audio pipeline");
    audio_pipeline_register(pipeline, bt_stream_reader, "bt");
    audio_pipeline_register(pipeline, i2s_stream_writer, "i2s");


    ESP_LOGI(TAG, "Link it together [Bluetooth]-->bt_stream_reader-->i2s_stream_writer-->[codec_chip]");
    rsp_filter_cfg_t rsp_cfg = DEFAULT_RESAMPLE_FILTER_CONFIG();
    rsp_cfg.src_rate = 44100;
    rsp_cfg.src_ch = 2;
    rsp_cfg.dest_rate = 48000;
    rsp_cfg.dest_ch = 2;
    audio_element_handle_t filter = rsp_filter_init(&rsp_cfg);
    audio_pipeline_register(pipeline, filter, "filter");
    i2s_stream_set_clk(i2s_stream_writer, 48000, 16, 2);
    const char *link_tag[3] = {"bt", "filter", "i2s"};
    audio_pipeline_link(pipeline, &link_tag[0], 3);


    ESP_LOGI(TAG, "Initialize peripherals");
    esp_periph_config_t periph_cfg = DEFAULT_ESP_PERIPH_SET_CONFIG();
    esp_periph_set_handle_t set = esp_periph_set_init(&periph_cfg);

    //ESP_LOGI(TAG, "Initialize Touch peripheral");
    //audio_board_key_init(set);

    ESP_LOGI(TAG, "Create Bluetooth peripheral");
    esp_periph_handle_t bt_periph = bluetooth_service_create_periph();

    ESP_LOGI(TAG, "Start all peripherals");
    esp_periph_start(set, bt_periph);

    ESP_LOGI(TAG, "Set up  event listener");
    audio_event_iface_cfg_t evt_cfg = AUDIO_EVENT_IFACE_DEFAULT_CFG();
    audio_event_iface_handle_t evt = audio_event_iface_init(&evt_cfg);

    ESP_LOGI(TAG, "Listening event from all elements of pipeline");
    audio_pipeline_set_listener(pipeline, evt);

    ESP_LOGI(TAG, "Listening event from peripherals");
    audio_event_iface_set_listener(esp_periph_set_get_event_iface(set), evt);

    ESP_LOGI(TAG, "Start audio_pipeline");
    audio_pipeline_run(pipeline);
// ******************************************************************

    while(1){

        audio_event_iface_msg_t msg;
        audio_event_iface_listen(evt, &msg, portMAX_DELAY);

        if (msg.source_type == AUDIO_ELEMENT_TYPE_ELEMENT && msg.source == (void *) bt_stream_reader && msg.cmd == AEL_MSG_CMD_REPORT_MUSIC_INFO) {
            
            audio_element_info_t music_info = {0};
            audio_element_getinfo(bt_stream_reader, &music_info);

            audio_element_setinfo(i2s_stream_writer, &music_info);

            i2s_stream_set_clk(i2s_stream_writer, music_info.sample_rates, music_info.bits, music_info.channels);
            continue;
        }


               // Stop when the Bluetooth is disconnected or suspended
        if (msg.source_type == PERIPH_ID_BLUETOOTH
            && msg.source == (void *)bt_periph) {
            if (msg.cmd == PERIPH_BLUETOOTH_DISCONNECTED) {
                ESP_LOGW(TAG, "[ * ] Bluetooth disconnected");
                break;
            }
        }
        // Stop when the last pipeline element (i2s_stream_writer in this case) receives stop event
        if (msg.source_type == AUDIO_ELEMENT_TYPE_ELEMENT && msg.source == (void *) i2s_stream_writer
            && msg.cmd == AEL_MSG_CMD_REPORT_STATUS
            && (((int)msg.data == AEL_STATUS_STATE_STOPPED) || ((int)msg.data == AEL_STATUS_STATE_FINISHED))) {
            ESP_LOGW(TAG, "[ * ] Stop event received");
            break;
        }

    }



    ESP_LOGI(TAG, "Stop audio_pipeline");
    audio_pipeline_stop(pipeline);
    audio_pipeline_wait_for_stop(pipeline);
    audio_pipeline_terminate(pipeline);

    audio_pipeline_unregister(pipeline, bt_stream_reader);
    audio_pipeline_unregister(pipeline, i2s_stream_writer);

    /* Terminate the pipeline before removing the listener */
    audio_pipeline_remove_listener(pipeline);

    /* Stop all peripherals before removing the listener */
    esp_periph_set_stop_all(set);
    audio_event_iface_remove_listener(esp_periph_set_get_event_iface(set), evt);

    /* Make sure audio_pipeline_remove_listener & audio_event_iface_remove_listener are called before destroying event_iface */
    audio_event_iface_destroy(evt);

    // Release all resources

    audio_pipeline_unregister(pipeline, filter);
    audio_element_deinit(filter);


}

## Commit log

2021-01-21 Added connector reset line. System will be powered down if no cable is attached
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2021-02-08 Added an Eagle design block for TPA3244
    [Slutsteg.sch]
2021-02-09 Renamed folder and added entries to .gitignore
    [Slutsteg.brd, Slutsteg.sch]
2021-02-11 Might be done with the schematic
2021-02-11 Flyttat teorimappen och lagt till lite dokument om filter
2021-02-18 Added the TPA3244 design block to the schematic and updated the coils.
    [Slutsteg.brd, Slutsteg.sch]
2021-02-18 Temporary layout to see the size of the card.
    [Slutsteg.brd]
2021-02-18 Minor changes to the layout
    [Slutsteg.brd]
2021-02-18 Fixed minor issues with TPA3251 design block and added it to the schematic.
    [Slutsteg.brd, Slutsteg.sch]
2021-02-18 Fixed missing page.
    [Slutsteg.sch]
2021-02-24 Fixed issues with the original schematic. No ERC errors!
2021-02-24 Added example files for a F-6888 BLE module
    [F-6888_UART.xls, F-6888_UART_EN.xlsx, UART通讯命令.xls]
2021-02-24 Added Software for ESP32 BLE audio sink.
    [partitions_bt_sink_example.csv]
2021-02-24 Changed value of main bulk capacitors to the 1000uF version of the same capacitor
2021-02-24 Changed capacitor size to match the TPA3251 design. Changed bulk capacitors to 1000uF to match TPA3251.
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2021-02-24 Updated the schematic with the new designblocks
    [Slutsteg.brd, Slutsteg.sch]
2021-02-24 Helt nytt filter typ
    Lagt till stereo-ingång som helt ahde missats innan. SUmmator för basen som summerar Vänster/Höger.
    Ska färdigställa volymknobb
2021-02-25 Ändrat HP-filtrerna till Sallen-Key
    Lagt till volymändring och ändrat HP-filtrerna till Sallen-Key (igen) pga nån snubbe https://sound-au.com/articles/active-filters.htm
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2021-02-26 Changed to the internal regulator would not drive the pullups. External 3.3V DC/DC is needed
    [Slutsteg.brd, Slutsteg.sch]
2021-02-26 Did the layout for TPA3244 and added 3D-models for those components
    [Slutsteg.brd, Slutsteg.sch]
2021-02-26 Added the ESP32 board and placed it in the layout.
    [Slutsteg.brd, Slutsteg.sch]
2021-02-26 Added speaker connector models.
    [Slutsteg.brd, Slutsteg.sch]
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2021-03-04 Sammanfogat design blocks
    [Slutsteg.brd, Slutsteg.sch]
2021-03-04 Minor changes to ESP32 implementation
    [Slutsteg.brd, Slutsteg.sch]
2021-03-04 Renumbered components.
    [Slutsteg.brd, Slutsteg.sch]
2021-03-04 Updated components value
    [Slutsteg.brd, Slutsteg.sch]
2021-03-04 Changed some component footprints and simplified the V-Reg configuration
    [Slutsteg.brd, Slutsteg.sch]
2021-03-04 Changed OP-AMP for the DAC
    [Slutsteg.brd, Slutsteg.sch]
2021-03-04 Changed footprints for caps
    [Slutsteg.brd, Slutsteg.sch]
2021-03-04 Changed components
    [Slutsteg.brd, Slutsteg.sch]
2021-03-04 Lagt till 3.5mm connector
    [Slutsteg.brd, Slutsteg.sch]
2021-03-04 Revert "Lagt till 3.5mm connector"
    This reverts commit b586c7d4102b99b6a6c1c70b6fd3026c9e3e15a7.
    [Slutsteg.brd, Slutsteg.sch]
2021-03-04 Lagt till 3.5mm input och vridpot för Basen
    [Slutsteg.brd, Slutsteg.sch]
2021-03-04 FIxat lite kondensatorer
    :)
    [Slutsteg.brd, Slutsteg.sch]
2021-03-04 Fixa en sista kondensator
    :DDDDDDD
    [Slutsteg.brd, Slutsteg.sch]
2021-03-04 En halvdan bom
    Enbart länkar än så länge
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2021-03-04 Snyggat till kopplingar
    [Slutsteg.brd, Slutsteg.sch]
2021-03-06 fixade lite graj
    [Slutsteg.brd, Slutsteg.sch]
2021-03-06 Börjat med TPA3251s del av kretskortet
    [Slutsteg.brd, Slutsteg.sch]
2021-03-06 Lagt till double-gang pot och petat lite i layouten
    [Slutsteg.brd, Slutsteg.sch]
2021-03-06 Continued with layout and fixed minor issues with the schematic.
    [Slutsteg.brd, Slutsteg.sch]
2021-03-07 ALmost done with the ESP32 & TPA3244 layout
    [Slutsteg.brd, Slutsteg.sch]
2021-03-08 Lagt till artikelnummer och inköpsantal
    [BOMv1.xlsx]
2021-03-08 Uppdaterad och skickad till Arta
    Skickad de poster som var till ELFA och RS. Uppdaterad nya kolumner för inköp med marginal. Måste göra klart de vi köper själva från Digikey
    [BOMv1.xlsx]
2021-03-08 started on the smaller components
    [Slutsteg.brd, Slutsteg.sch]
2021-03-08 PCB-layout: dragit till första opampstegen
    [Slutsteg.brd, Slutsteg.sch]
2021-03-08 Lagt till mer rader i BOMEN
    [BOMv1.xlsx]
2021-03-08 Connected more things in the layout. Added a heatsink and lib file for it.
    [Slutsteg.brd, Slutsteg.sch]
2021-03-09 Reduced I2C bit size in bitstream from 24-16.
2021-03-09 small tweaks
    [Slutsteg.brd]
2021-03-09 PANIC, lagt till extra OP
    Kör DIFF input på alla klass D
    [Slutsteg.brd, Slutsteg.sch]
2021-03-09 Cleaned up TPA3251
    [Slutsteg.brd, Slutsteg.sch]
2021-03-09 Uppdaterat lite extra poster
    [BOMv1.xlsx]
2021-03-09 Almost done with first draft of layout.
    [Slutsteg.brd, Slutsteg.sch]
2021-03-09 First draft of layout is finished. No DRC warnings.
    [Slutsteg.brd]
2021-03-09 fixade stavfel i BOM
    [BOMv1.xlsx]
2021-03-09 Added some test points. More to come....
    [Slutsteg.brd, Slutsteg.sch]
2021-03-09 TPs och Viastiching
    TP,VIAstich,borrhål
    [Slutsteg.brd, Slutsteg.sch]
2021-03-10 Moved labels in layout.
    [Slutsteg.brd, Slutsteg.sch]
2021-03-10 Finished the first draft and exported the Gerber files.
    [Slutsteg.brd]
2021-03-10 Added a header for the cooling fan.
    [Slutsteg.brd, Slutsteg.sch]
2021-03-12 Pillar lite med ny BOM
    Fortfarande lite rörigt
    [BOMv1.xlsx, Final_BOM.xlsx]
2021-05-02 Added housing for the electronics and PSU.
    [Housing_Bottom.STEP, Housing_Bottom.STL, Housing_Top.STL]
2021-05-09 Added frequency response of the speaker
    [100Procent-Bas.csv, 100Procent-Diskant.csv, 20Procent-Båda.csv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]
2021-05-11 Added images for magnitude response
    [100Procent-Båda.csv]
2021-05-13 A final render of the board
    Much cool! Very wow!
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

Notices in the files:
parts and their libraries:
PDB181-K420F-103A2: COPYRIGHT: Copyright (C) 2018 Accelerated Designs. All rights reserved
